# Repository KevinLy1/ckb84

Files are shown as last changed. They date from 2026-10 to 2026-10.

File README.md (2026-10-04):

# CKB84
A DIY custom keyboard with 84 keys with per-key rgb and hotswappable keys.
Raspberry Pi RP2040 MCU.

## Features
- Hotswappable
- Per-key RGB Backlight
- 75% Layout
- QMK and Vial support
- 3D printed / CNC case and plate
- Custom layout : Backspace 2u, Left Shift 2u, Right Shift 2u, ISO Enter, Spacebar 6u

# Images

## Layout

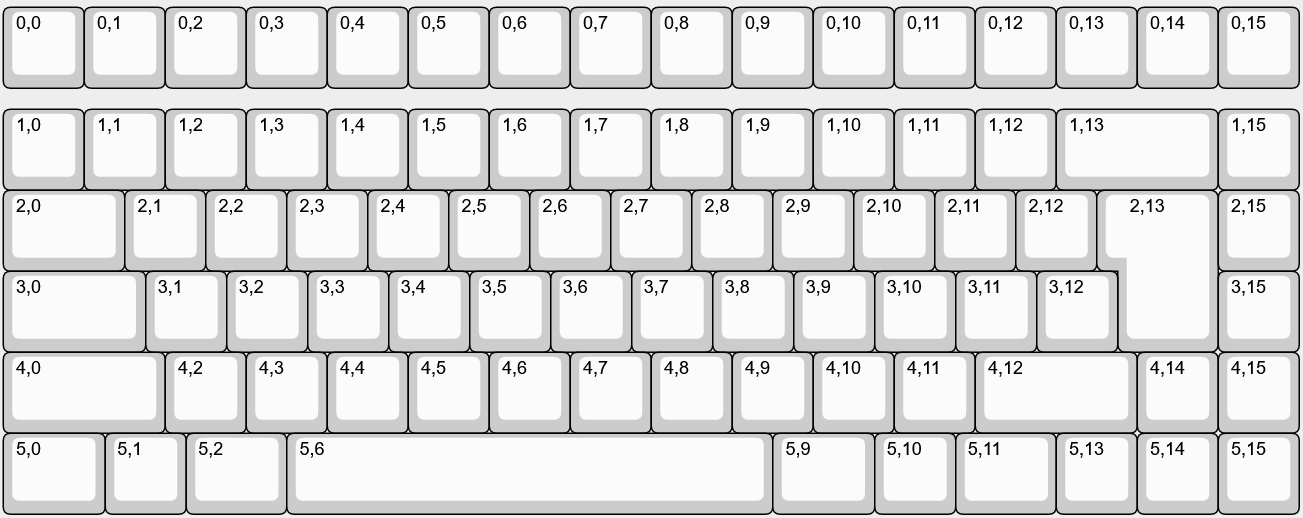
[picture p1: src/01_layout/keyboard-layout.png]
Keyboard layout


## PCB

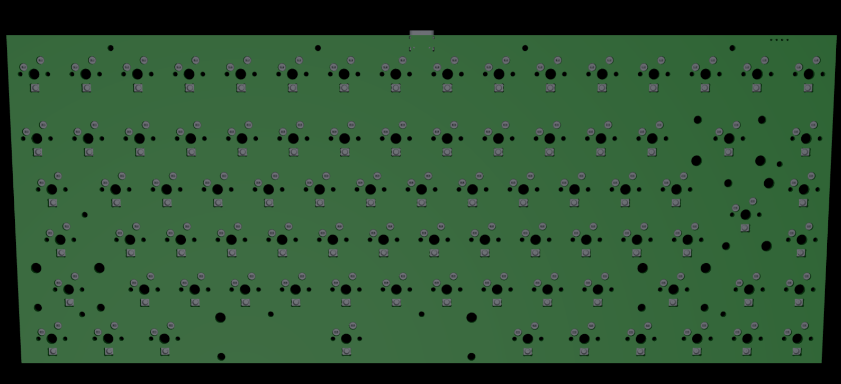
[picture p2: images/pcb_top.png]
PCB Top

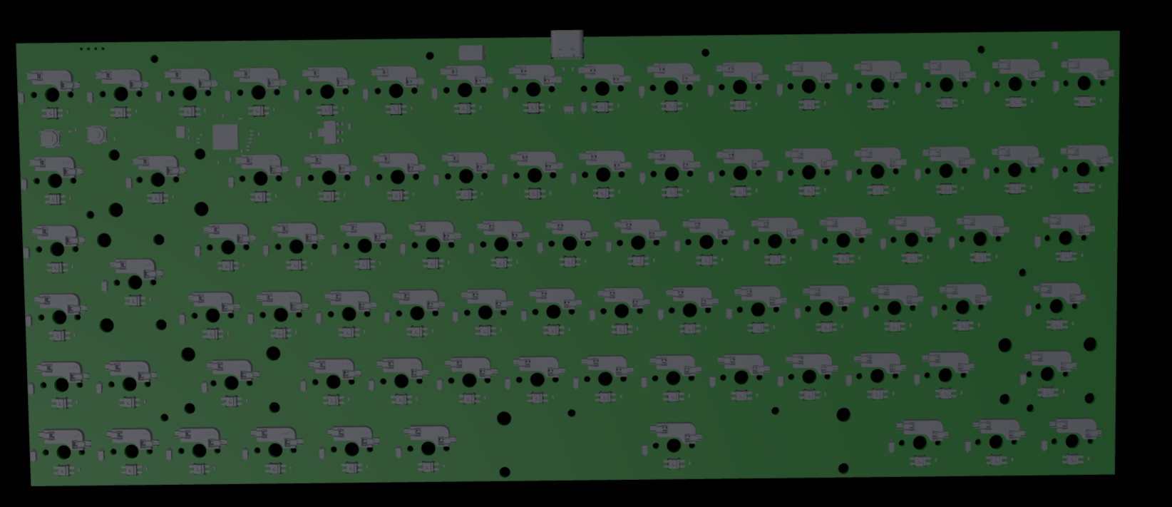
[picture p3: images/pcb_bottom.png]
PCB Bottom


## Case and Plate

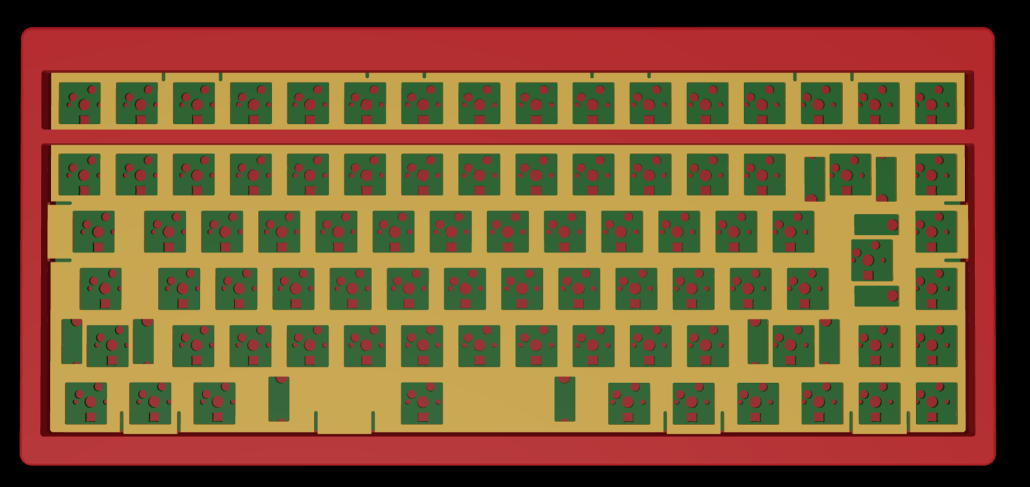
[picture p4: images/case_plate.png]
Case + Plate

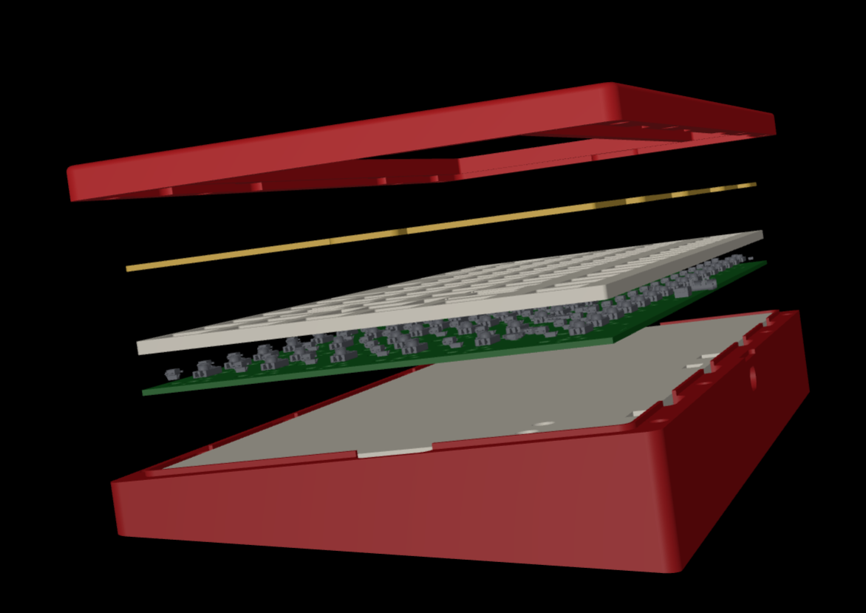
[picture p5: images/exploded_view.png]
Exploded view


## Firmware

See [QMK Reproducible](https://github.com/KevinLy1/qmk_reproducible) -> diy/ckb84.

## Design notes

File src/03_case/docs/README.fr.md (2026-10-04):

# Clavier 75 % sur mesure : boîtier gasket-mount

Boîtier usiné CNC, avec une plaque montée sur joints en Poron et des aimants à la place des vis. Tout est généré à partir du PCB KiCad de `src/02_pcb`, par les scripts build123d de `src/`.

| Caractéristique | Valeur |
|---|---|
| Dimensions | **319,8 × 143,8 mm**, 148 mm de profondeur posé sur le bureau |
| Hauteur (avant / arrière) | **22,1 / 42,1 mm** |
| Angle de frappe | **8°**, donné par le bottom case en coin |
| Masse | top case ≈ 87 g + bottom case ≈ 655 g |
| Montage | 10 pattes de plaque entre des pastilles de Poron |
| Fermeture | 8 paires d'aimants 5 × 2 mm |

## Construction

Depuis `src/03_case`, avec Docker Desktop lancé (environnement figé, build123d 0.13.0) :

```bash
docker compose build
```

```bash
docker compose run --rm cad src/build_all.py
```

```bash
docker compose run --rm cad src/drawings.py
```

```bash
docker compose run --rm cad src/docs_html.py
```

Pour servir le viewer, puis ouvrir `http://localhost:8765/out/viewer.html` :

```bash
docker compose run --rm --service-ports cad -m http.server 8765
```

`build_all.py` vérifie aussi qu'aucune pièce n'en chevauche une autre (tous les résultats doivent valoir `0.0`). Ré-exporter `in/pcb.step` et `in/pcb_full.step` après une modification du PCB demande `kicad-cli` sur la machine.

## Résumé de la conception

Empilement (dessus du PCB = 0, en mm) : PCB −1,51 … 0, plaque 3,5 … 5,0, joints 3,0 (compressés à 2,4), plan de jonction 5,0, dessus 14,0, fond de cavité −6,51.

- **Plaque :** 1,5 mm, découpes de switches 14 × 14 mm, découpes de stabilisateurs Cherry à visser, 10 pattes de joint avec fentes de flexion. Les positions viennent des empreintes KiCad.
- **Top case :** cadre de 9 mm avec un pont de 4,5 mm sur la rangée F.
- **Bottom case :** cavité parallèle à la plaque, rebord de centrage, ouverture USB-C avec une peau de 1 mm pour ne laisser voir que le port, encoche de levage à l'arrière, dessous à 8° avec quatre logements de Ø10,4 pour les patins.
- **Stabilisateurs :** S5 est dans l'orientation Cherry standard, S1–S4 sont tournés de 180° sur le PCB. La plaque suit le PCB, elle s'adapte donc telle quelle.

## Fabrication

- **Top case :** 2 mises en position. **Bottom case :** 3 mises en position (face de jonction, dessous à 8°, ouverture USB-C sur la face arrière).
- **Prototype d'abord :** imprime les STL en 3D pour vérifier l'assemblage avant de payer l'usinage.

## Liste d'achats (amazon.fr)

| # | Article | Qté | Caractéristiques | Recherche sur amazon.fr |
|---|---|---|---|---|
| 1 | Aimants néodyme | 16 (8 paires) + rechange | Disque **5 × 2 mm**, N52 | `aimant néodyme 5x2 mm` (lots de 50) |
| 2 | Mousse pour joints | 20 pastilles | **Poron 3 mm** (ou mousse EPDM 3 mm), adhésive ; à découper en pastilles de 15 × 3 mm | `poron 3mm adhésif` / `joint mousse EPDM adhésif 3 mm` |
| 3 | Patins en caoutchouc | 4 | Patins adhésifs plats **Ø10 × 3 mm** | `patins caoutchouc adhésifs 10 x 3 mm` |
| 4 | Mousse de fond | 1 feuille ≥ 310 × 130 mm | **3 mm**, Poron ou EVA (moins cher) ; découpe selon `case_foam.dxf` | `feuille mousse EVA 3 mm A3` |
| 5 | Mousse PCB/plaque (optionnelle) | 1 feuille | 3–3,5 mm, Poron ou PE, avec les trous des switches | `mousse polyuréthane 3 mm` |
| 6 | Colle | 1 | Cyanoacrylate en **gel** ou époxy bi-composant | `colle cyanoacrylate gel` / `Araldite` |

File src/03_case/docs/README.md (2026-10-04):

# Custom 75 % keyboard: gasket-mount case

CNC-machined case with a gasket-mounted plate (Poron pads) and magnets instead of screws. Everything is generated from the KiCad board in `src/02_pcb` by the build123d scripts in `src/`.

| Feature | Value |
|---|---|
| Outside size | **319.8 × 143.8 mm**, 148 mm deep on the desk |
| Height (front / back) | **22.1 / 42.1 mm** |
| Typing angle | **8°**, from the wedge-shaped bottom case |
| Mass | top case ≈ 87 g + bottom case ≈ 655 g |
| Mount | 10 plate tabs between Poron pads |
| Closure | 8 pairs of 5 × 2 mm magnets |

## Build

From `src/03_case`, with Docker Desktop running (pinned environment, build123d 0.13.0):

```bash
docker compose build
```

```bash
docker compose run --rm cad src/build_all.py
```

```bash
docker compose run --rm cad src/drawings.py
```

```bash
docker compose run --rm cad src/docs_html.py
```

Serve the viewer, then open `http://localhost:8765/out/viewer.html`:

```bash
docker compose run --rm --service-ports cad -m http.server 8765
```

`build_all.py` also checks that no two parts overlap (all results must be `0.0`). Re-exporting `in/pcb.step` and `in/pcb_full.step` after a PCB change needs `kicad-cli` on the host.

## Design summary

Stack-up (PCB top = 0, in mm): PCB −1.51 … 0, plate 3.5 … 5.0, gasket pads 3.0 (compressed to 2.4), parting plane 5.0, top surface 14.0, cavity floor −6.51.

- **Plate:** 1.5 mm, 14 × 14 mm switch cutouts, Cherry screw-in stabilizer cutouts, 10 gasket tabs with flex slots. Positions come from the KiCad footprints.
- **Top case:** 9 mm frame with a 4.5 mm F-row bridge.
- **Bottom case:** cavity parallel to the plate, alignment lip, USB-C slot with a 1 mm skin so only the port shows, pry notch at the back, underside at 8° with four Ø10.4 recesses for rubber feet.
- **Stabilizers:** S5 is in the standard Cherry orientation, S1–S4 are rotated 180° on the PCB. The plate follows the PCB, so it fits as is.

## Manufacturing

- **Top case:** 2 setups. **Bottom case:** 3 setups (parting face, 8° underside, USB-C slot on the back face).
- **Prototype first:** 3D-print the STLs to check the fit before paying for CNC.

## Hardware list (amazon.fr)

Search terms are in French where that finds the right product more easily.

| # | Item | Qty | Specification | Search on amazon.fr |
|---|---|---|---|---|
| 1 | Neodymium magnets | 16 (8 pairs) + spares | Disc **5 × 2 mm**, N52 | `aimant néodyme 5x2 mm` (packs of 50) |
| 2 | Gasket foam | 20 pads | **Poron 3 mm** (or EPDM sponge 3 mm), self-adhesive; cut into 15 × 3 mm pads | `poron 3mm adhésif` / `joint mousse EPDM adhésif 3 mm` |
| 3 | Rubber feet | 4 | **Ø10 × 3 mm** flat self-adhesive bumpers | `patins caoutchouc adhésifs 10 x 3 mm` |
| 4 | Case foam | 1 sheet ≥ 310 × 130 mm | **3 mm** Poron, or EVA as a cheaper option; cut from `case_foam.dxf` | `feuille mousse EVA 3 mm A3` |
| 5 | PCB/plate foam (optional) | 1 sheet | 3–3.5 mm Poron or PE, with switch holes | `mousse polyuréthane 3 mm` |
| 6 | Glue | 1 | Cyanoacrylate **gel** or 2-part epoxy | `colle cyanoacrylate gel` / `Araldite` |

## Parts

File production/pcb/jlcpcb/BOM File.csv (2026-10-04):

Designator | Footprint | Quantity | Value | LCSC Part #
C1 | CP_EIA-7343-31_Kemet-D | 1 | 470uF | C7229
C10, C17, C2, C3, C4, C5, C6, C7, C8, C9, LC1, LC10, LC11, LC12, LC13, LC14, LC15, LC16, LC17, LC18, LC19, LC2, LC20, LC21, LC22, LC23, LC24, LC25, LC26, LC27, LC28, LC29, LC3, LC30, LC31, LC32, LC33, LC34, LC35, LC36, LC37, LC38, LC39, LC4, LC40, LC41, LC42, LC43, LC44, LC45, LC46, LC47, LC48, LC49, LC5, LC50, LC51, LC52, LC53, LC54, LC55, LC56, LC57, LC58, LC59, LC6, LC60, LC61, LC62, LC63, LC64, LC65, LC66, LC67, LC68, LC69, LC7, LC70, LC71, LC72, LC73, LC74, LC75, LC76, LC77, LC78, LC79, LC8, LC80, LC81, LC82, LC83, LC84, LC9 | 0402 | 94 | 100nF | C1525
C11, C12 | 0402 | 2 | 1u | C52923
C13, C14 | 0603 | 2 | 22u | C59461
C15, C16 | 0402 | 2 | 15pF | C1548
D1, D10, D11, D12, D13, D14, D15, D16, D17, D18, D19, D2, D20, D21, D22, D23, D24, D25, D26, D27, D28, D29, D3, D30, D31, D32, D33, D34, D35, D36, D37, D38, D39, D4, D40, D41, D42, D43, D44, D45, D46, D47, D48, D49, D5, D50, D51, D52, D53, D54, D55, D56, D57, D58, D59, D6, D60, D61, D62, D63, D64, D65, D66, D67, D68, D69, D7, D70, D71, D72, D73, D74, D75, D76, D77, D78, D79, D8, D80, D81, D82, D83, D84, D9 | D_SOD-123 | 84 | D | C33221
J1 | USB_C_Receptacle_HRO_TYPE-C-31-M-12 | 1 | USB_C_Receptacle_USB2.0 | C165948
LED1, LED10, LED11, LED12, LED13, LED14, LED15, LED16, LED17, LED18, LED19, LED2, LED20, LED21, LED22, LED23, LED24, LED25, LED26, LED27, LED28, LED29, LED3, LED30, LED31, LED32, LED33, LED34, LED35, LED36, LED37, LED38, LED39, LED4, LED40, LED41, LED42, LED43, LED44, LED45, LED46, LED47, LED48, LED49, LED5, LED50, LED51, LED52, LED53, LED54, LED55, LED56, LED57, LED58, LED59, LED6, LED60, LED61, LED62, LED63, LED64, LED65, LED66, LED67, LED68, LED69, LED7, LED70, LED71, LED72, LED73, LED74, LED75, LED76, LED77, LED78, LED79, LED8, LED80, LED81, LED82, LED83, LED84, LED9 | LED_MX_6028R | 84 | MX_SK6812MINI-E | C5149201
MX1, MX10, MX11, MX12, MX13, MX14, MX15, MX16, MX17, MX18, MX19, MX2, MX20, MX21, MX22, MX23, MX24, MX25, MX26, MX27, MX28, MX29, MX3, MX30, MX31, MX33, MX34, MX35, MX36, MX37, MX38, MX39, MX4, MX40, MX41, MX42, MX43, MX44, MX45, MX46, MX48, MX49, MX5, MX50, MX51, MX52, MX53, MX54, MX55, MX56, MX57, MX58, MX59, MX6, MX60, MX61, MX62, MX63, MX64, MX65, MX66, MX67, MX68, MX69, MX7, MX70, MX71, MX72, MX73, MX74, MX76, MX78, MX8, MX80, MX82, MX83, MX84, MX9 | SW_MX_HS_CPG151101S11_1u | 78 | MX_SW_HS | C41430893
MX32 | SW_MX_HS_CPG151101S11_1.5u | 1 | MX_SW_HS | C41430893
MX47 | SW_MX_HS_CPG151101S11_1.75u | 1 | MX_SW_HS | C41430893
MX75, MX77, MX79, MX81 | SW_MX_HS_CPG151101S11_1.25u | 4 | MX_SW_HS | C41430893
R1, R2, R3 | 0402 | 3 | 5.1k | C25905
R4, R5 | 0402 | 2 | 27 | C226392
R6, R8 | 0402 | 2 | 1k | C11702
RST1, RST2 | SW_SPST_SKQG_WithStem | 2 | SW | C5140332
U1 | SOT-353_SC-70-5 | 1 | SN74LV1T34DCK | C48543212
U2 | SOT-223-3_TabPin2 | 1 | AMS1117-3.3 | C6186
U3 | SOT-23-6 | 1 | USBLC6-2SC6 | C558442
U4 | QFN-56-1EP_7x7mm_P0.4mm_EP3.2x3.2mm | 1 | RP2040 | C2040
U5 | SOIC127P790X216-8N | 1 | W25Q128JVS | C97521
Y1 | Crystal_SMD_3225-4Pin_3.2x2.5mm | 1 | ABM8-272-T3 | C20625731

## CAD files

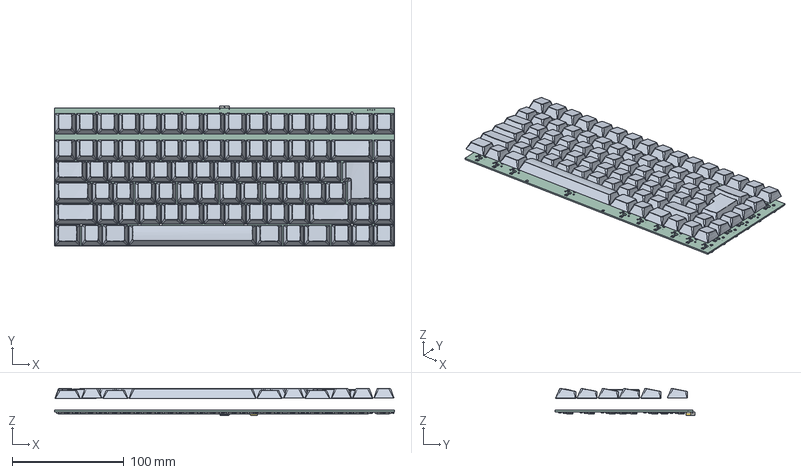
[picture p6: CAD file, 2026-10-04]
src/03_case/in/pcb_full.step
304.8 x 125.5 x 24.3 mm
C_0402_1005Metric x 98
D_SOD-123 x 84
R_0402_1005Metric x 8
C_0603_1608Metric x 2
Contact x 168
r4_100 x 73
LED_SK6812MINI-E v2 x 84
r3_125 x 4
QFN-56-1EP_7x7mm_P0.4mm_EP3.2x3.2mm
ConPins
PcbPins
Mold
Frame
SW_SPST_TL3342 x 2
r4_200 x 3
r4_175
r4_150
r4_600
Crystal_SMD_3225-4Pin_3.2x2.5mm
CP_EIA_7343_31_Kemet_D
SOT-23-6
SOT-223
r3_iso
SOT-353_SC-70-5
Custom_keyboard_PCB

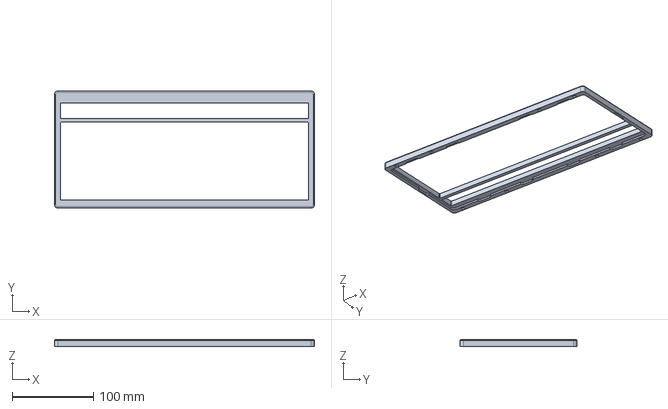
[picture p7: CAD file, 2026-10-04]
production/enclosure/top_case.step
319.8 x 143.8 x 9.00 mm

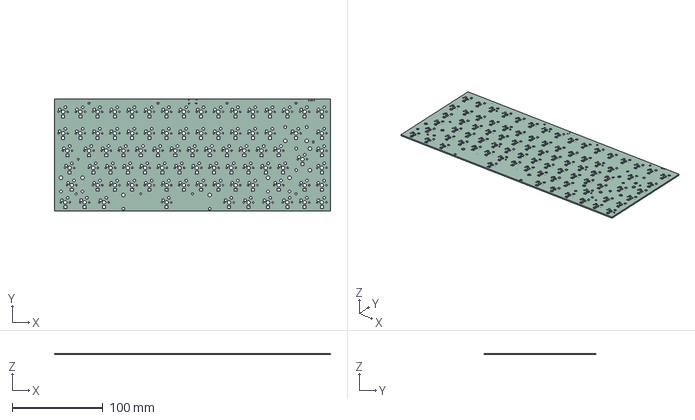
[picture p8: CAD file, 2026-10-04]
src/03_case/in/pcb.step
304.8 x 123.8 x 1.51 mm

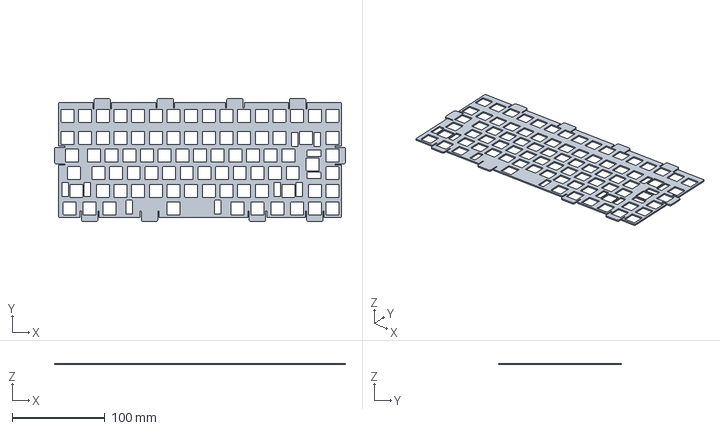
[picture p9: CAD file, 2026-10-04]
production/enclosure/plate.step
313.8 x 132.8 x 1.50 mm

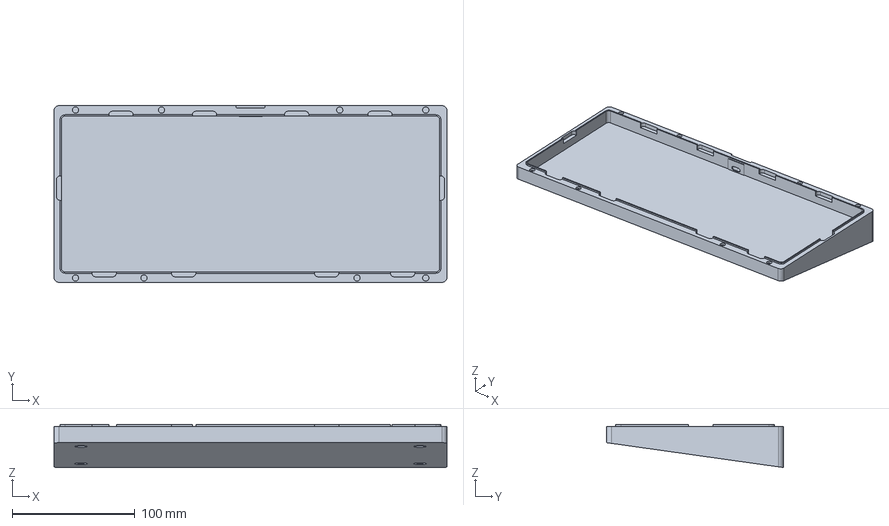
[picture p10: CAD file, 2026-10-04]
production/enclosure/bottom_case.step
319.8 x 143.8 x 35.0 mm

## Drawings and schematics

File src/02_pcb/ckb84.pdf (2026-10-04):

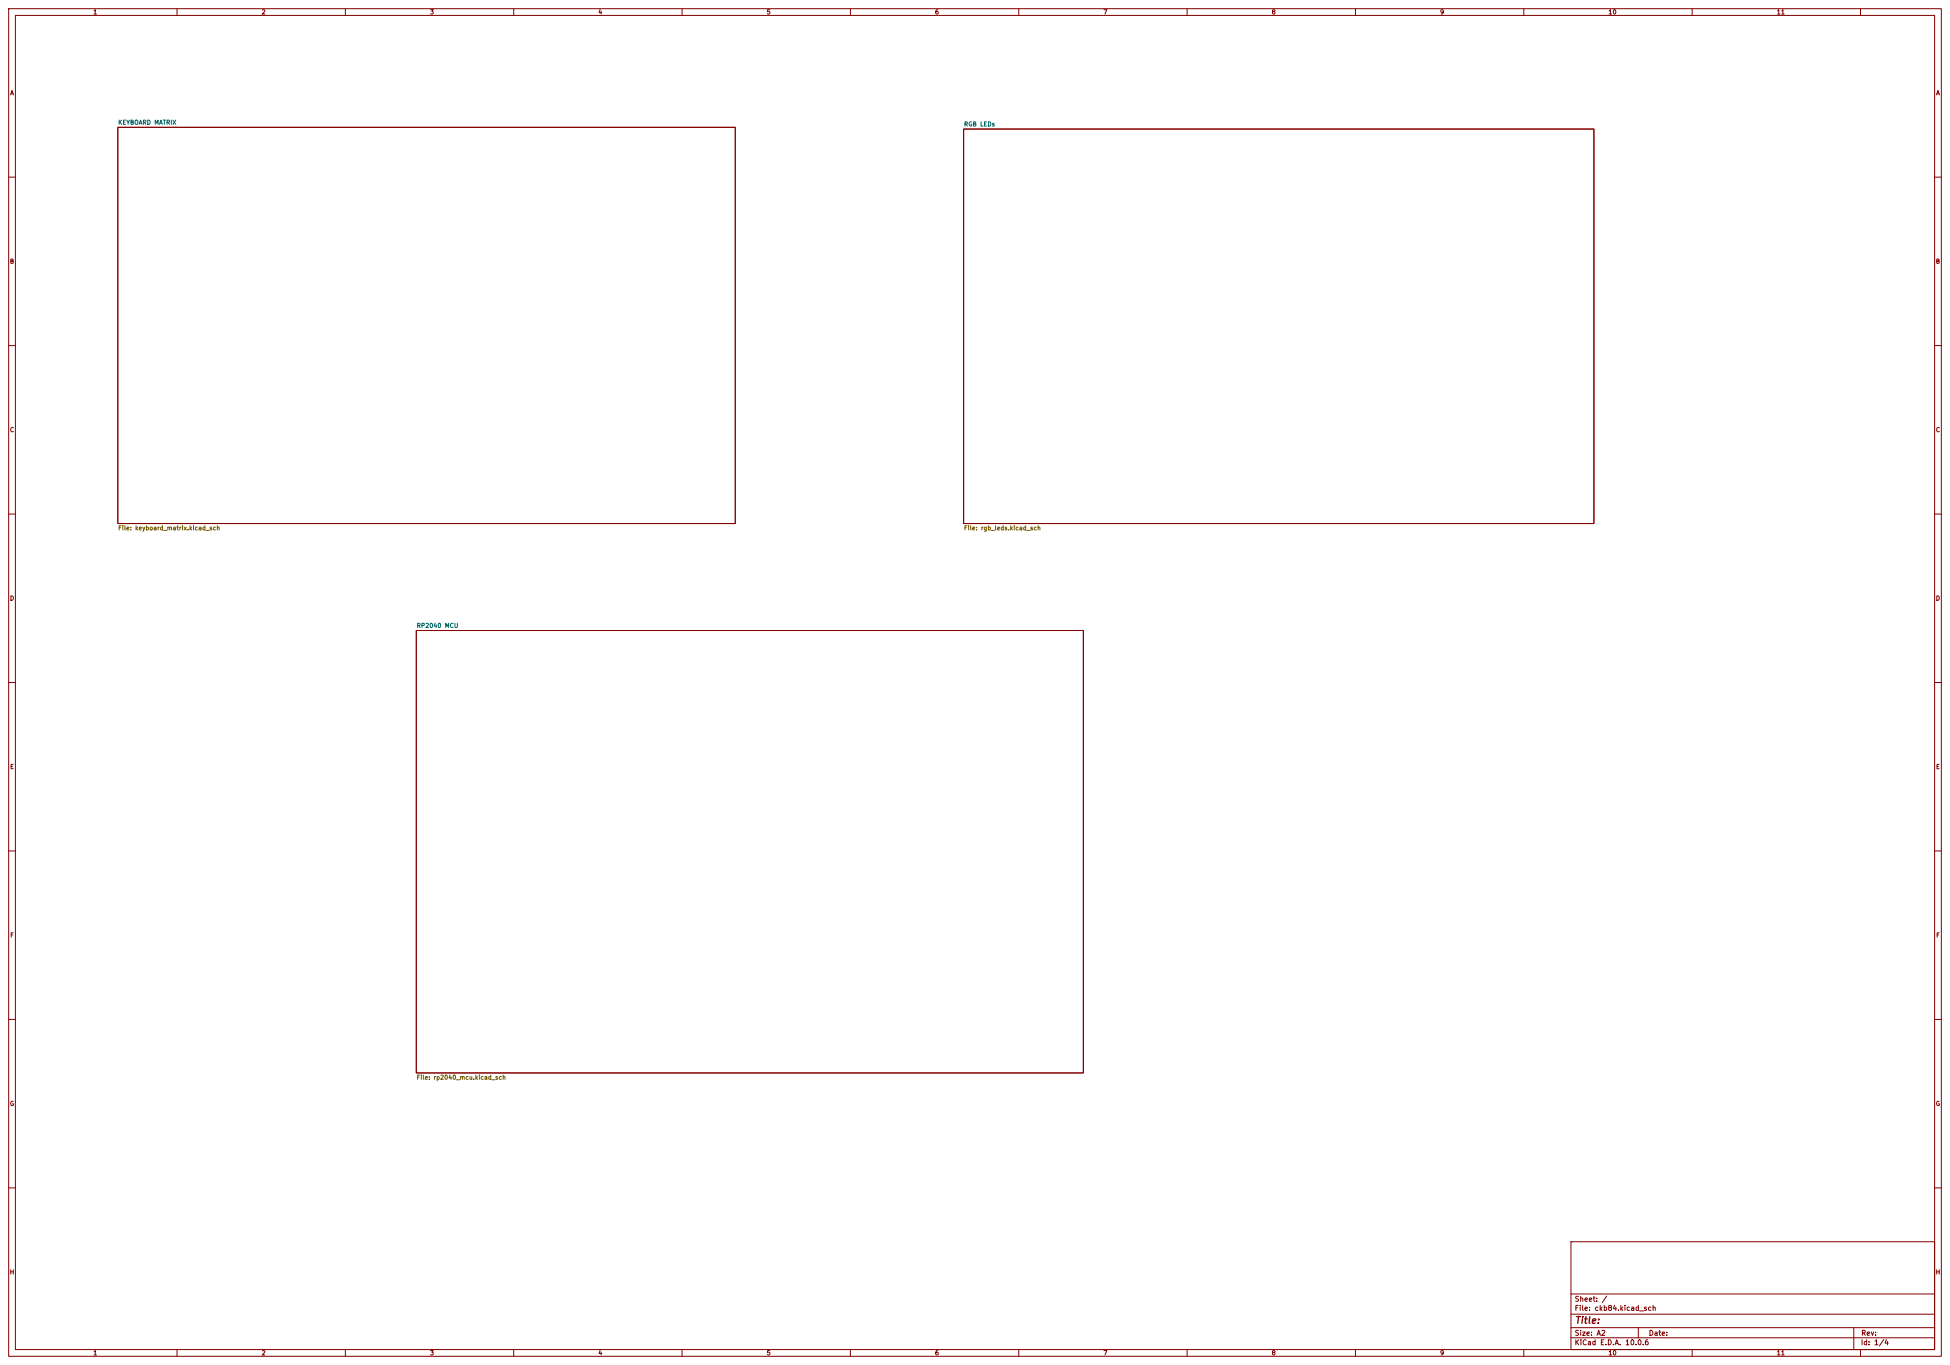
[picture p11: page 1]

Size: A2 | Rev:
KiCad E.D.A. 10.0.6 | Id: 1/4

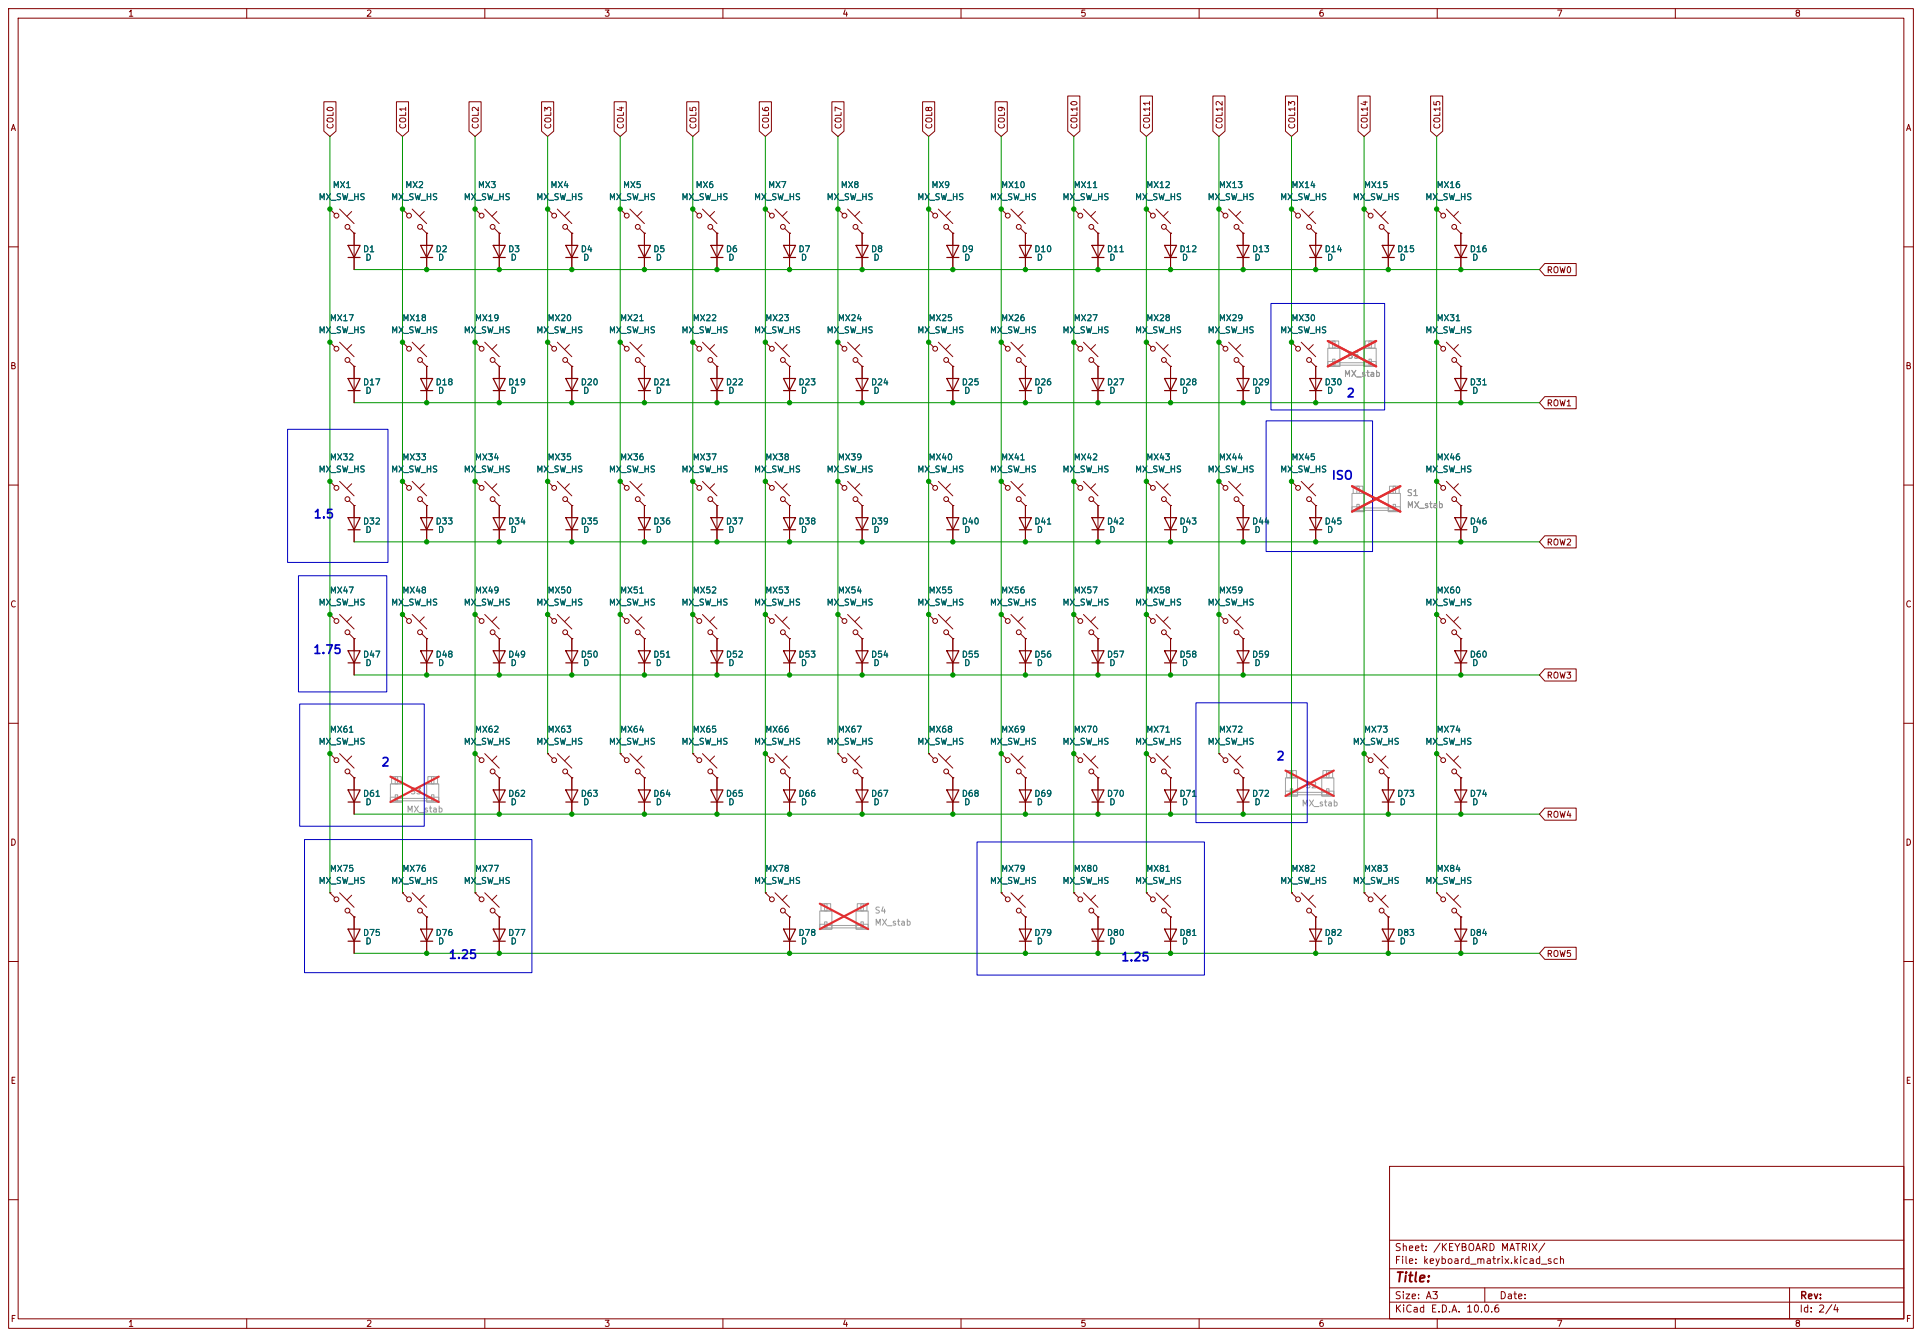
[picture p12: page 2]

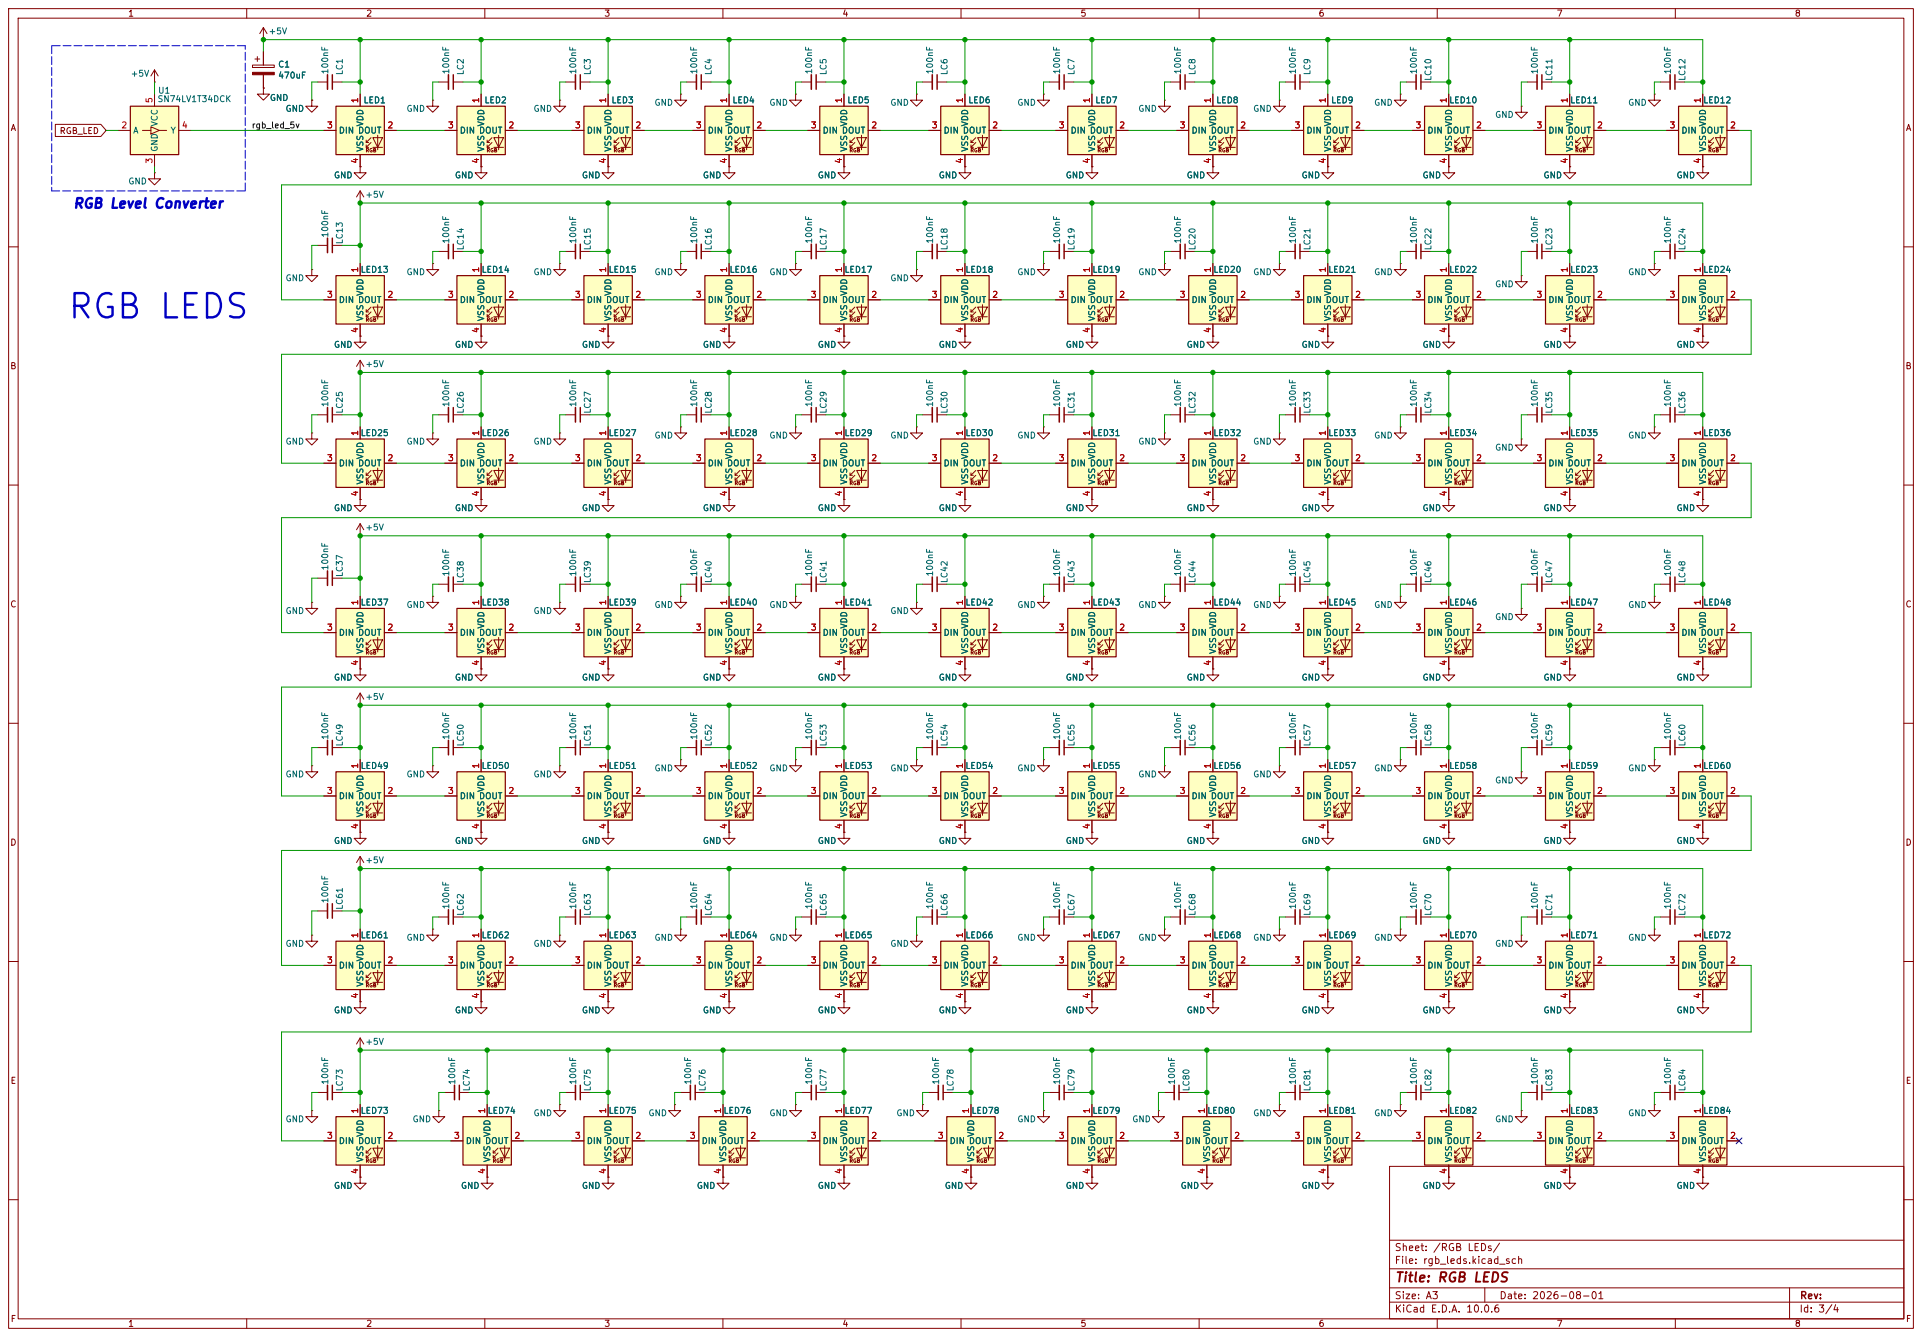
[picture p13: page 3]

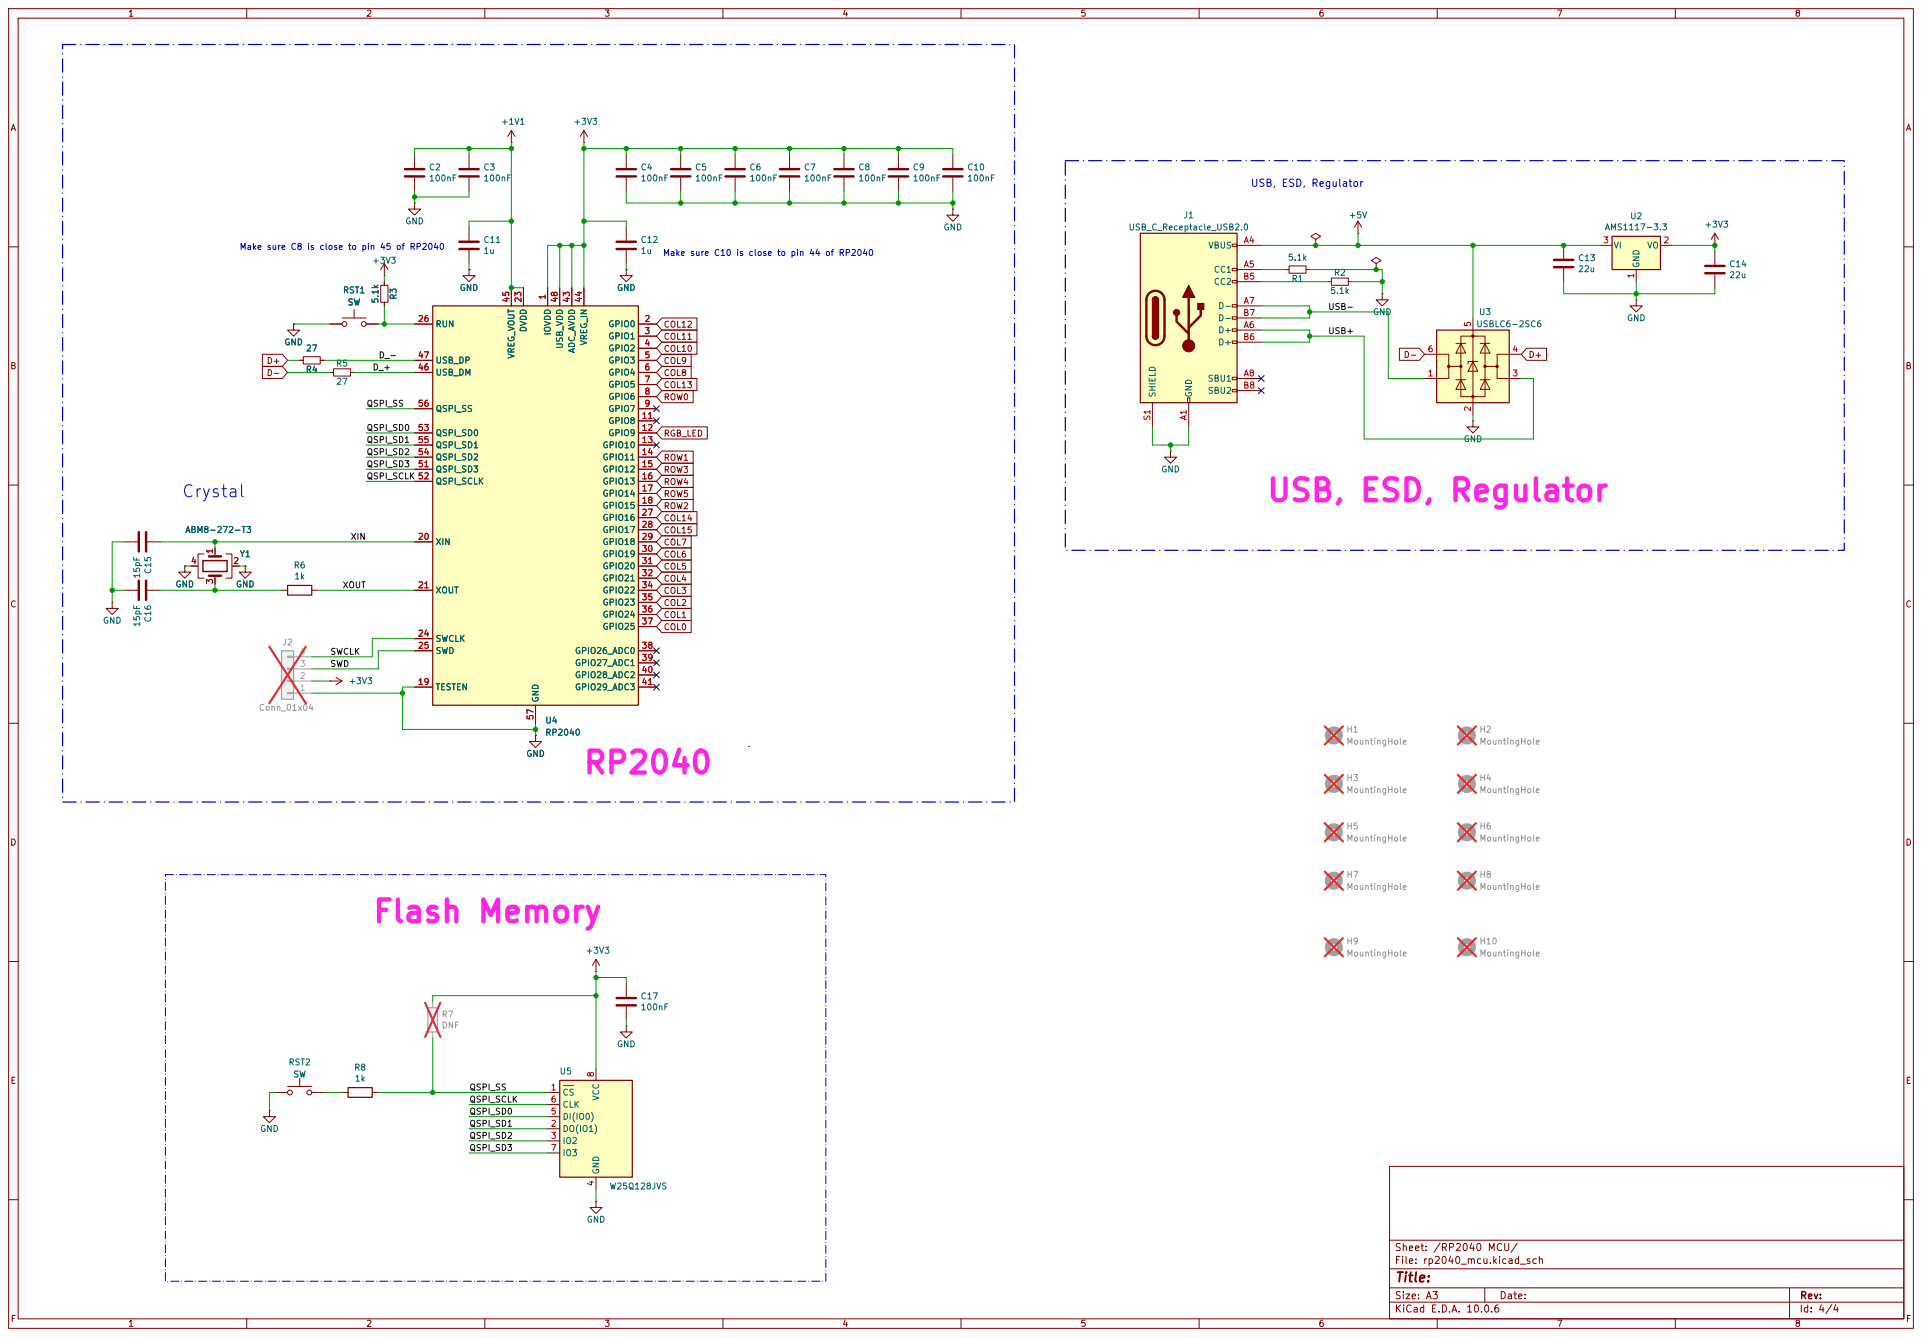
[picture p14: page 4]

Make sure C8 is close to pin 45 of RP2040 Crystal

Make sure C10 is close to pin 44 of RP2040 Flash Memory

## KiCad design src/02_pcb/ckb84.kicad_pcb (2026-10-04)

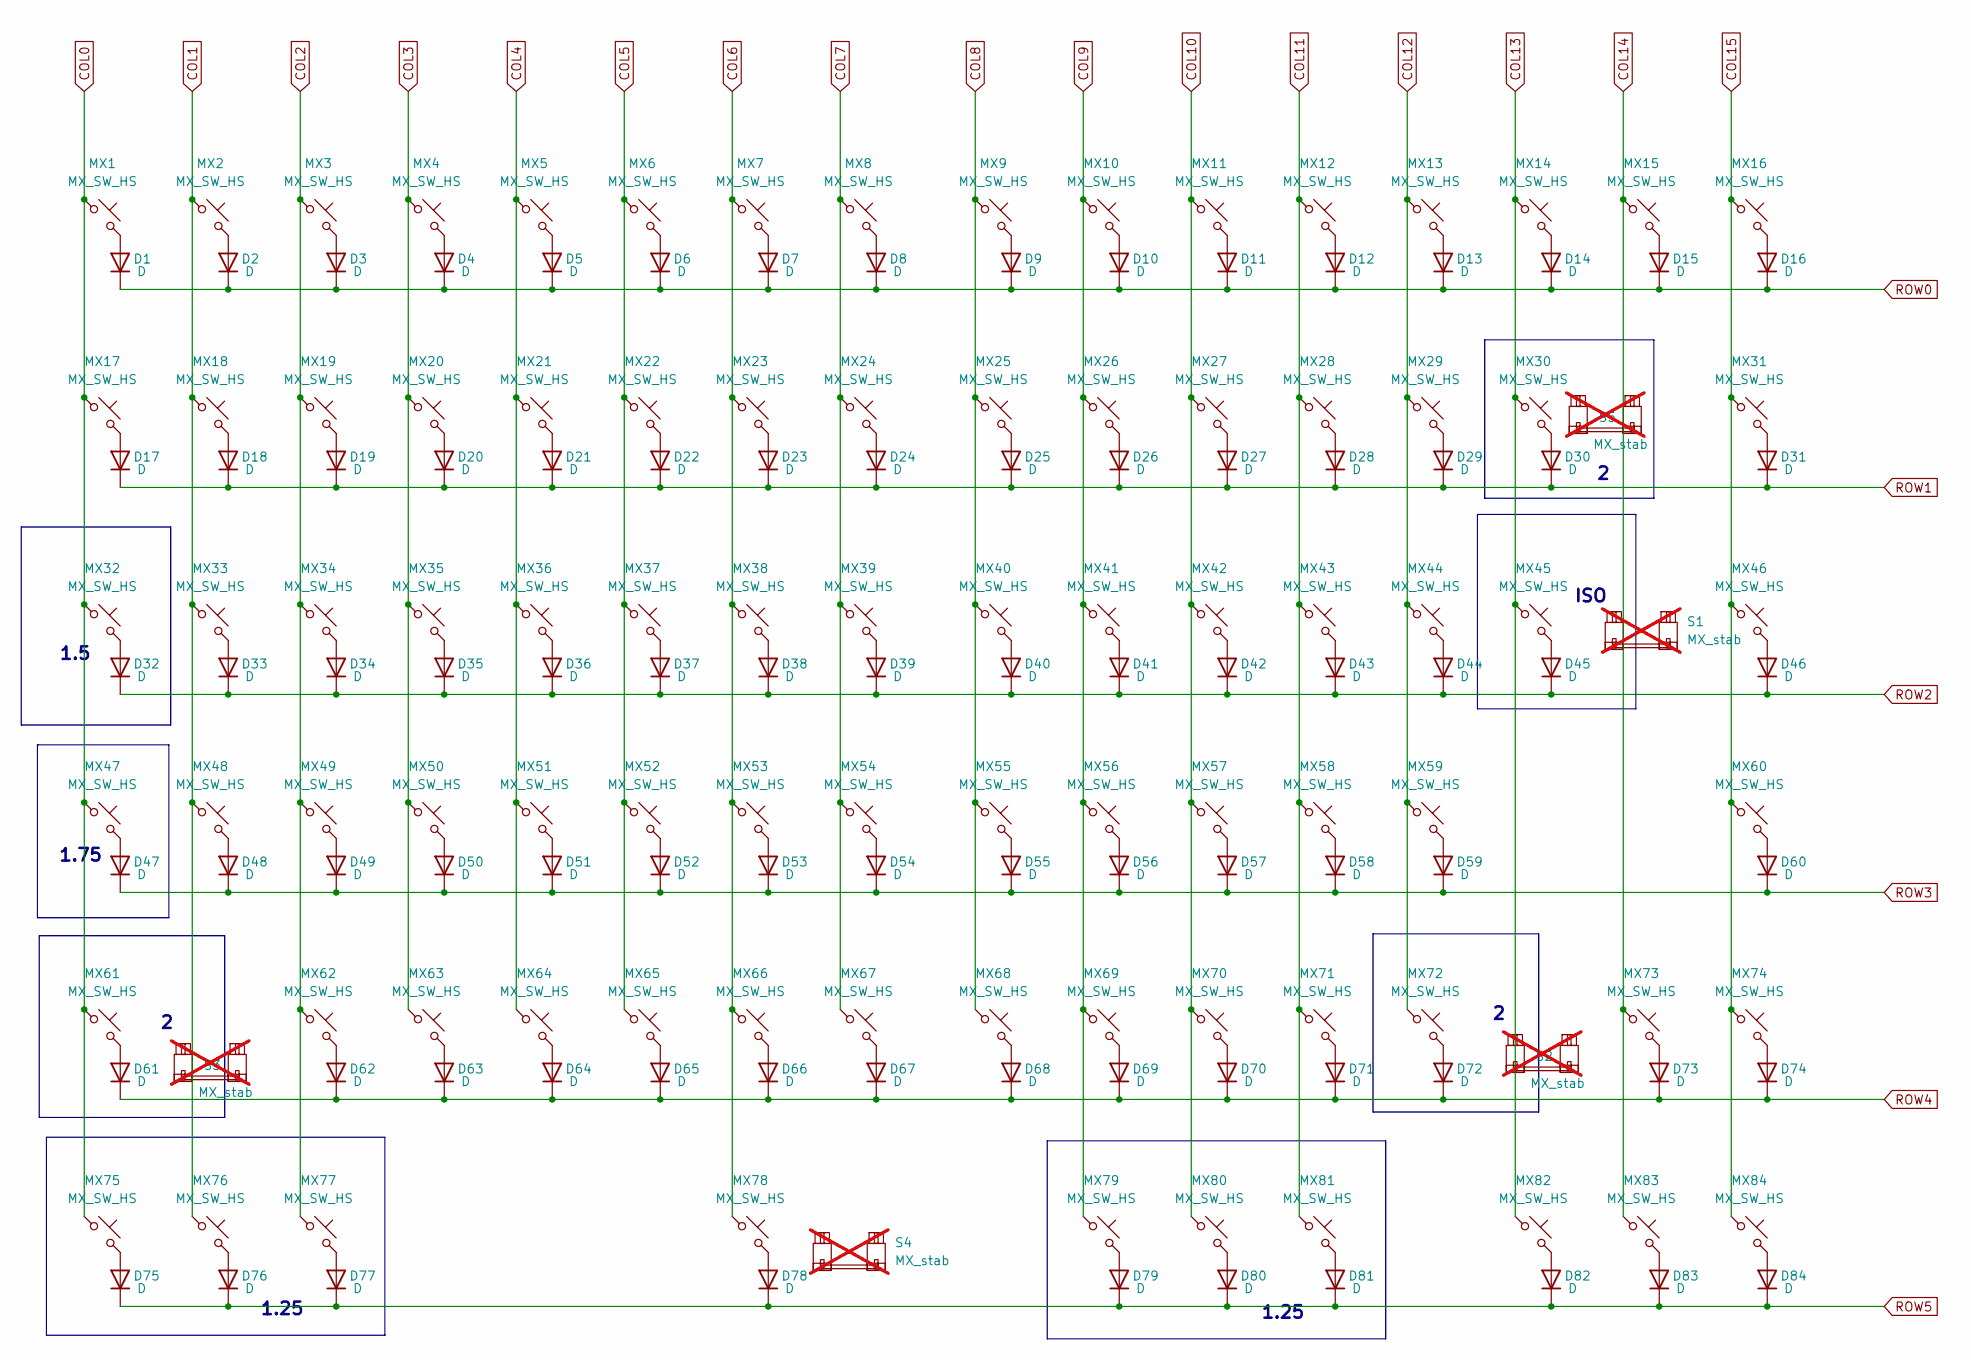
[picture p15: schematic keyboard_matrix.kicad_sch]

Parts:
D1, D2, D3, D4, D5, D6, D7, D8, D9, D10, D11, D12, D13, D14, D15, D16, D17, D18, D19, D20, D21, D22, D23, D24, D25, D26, D27, D28, D29, D30, D31, D32, D33, D34, D35, D36, D37, D38, D39, D40, D41, D42, D43, D44, D45, D46, D47, D48, D49, D50, D51, D52, D53, D54, D55, D56, D57, D58, D59, D60, D61, D62, D63, D64, D65, D66, D67, D68, D69, D70, D71, D72, D73, D74, D75, D76, D77, D78, D79, D80, D81, D82, D83, D84: D; D_SOD-123; MFR.Part # SOD1F7; LCSC C33221
MX1, MX2, MX3, MX4, MX5, MX6, MX7, MX8, MX9, MX10, MX11, MX12, MX13, MX14, MX15, MX16, MX17, MX18, MX19, MX20, MX21, MX22, MX23, MX24, MX25, MX26, MX27, MX28, MX29, MX30, MX31, MX33, MX34, MX35, MX36, MX37, MX38, MX39, MX40, MX41, MX42, MX43, MX44, MX45, MX46, MX48, MX49, MX50, MX51, MX52, MX53, MX54, MX55, MX56, MX57, MX58, MX59, MX60, MX61, MX62, MX63, MX64, MX65, MX66, MX67, MX68, MX69, MX70, MX71, MX72, MX73, MX74, MX76, MX78, MX80, MX82, MX83, MX84: MX_SW_HS; SW_MX_HS_CPG151101S11_1u; MFR.Part # CPG151101S11-16; LCSC C41430893
MX32: MX_SW_HS; SW_MX_HS_CPG151101S11_1.5u; MFR.Part # CPG151101S11-16; LCSC C41430893
MX47: MX_SW_HS; SW_MX_HS_CPG151101S11_1.75u; MFR.Part # CPG151101S11-16; LCSC C41430893
MX75, MX77, MX79, MX81: MX_SW_HS; SW_MX_HS_CPG151101S11_1.25u; MFR.Part # CPG151101S11-16; LCSC C41430893
S1: MX_stab; STAB_MX_ISO; MFR.Part # DNP; JLCPCB part# DNP; not fitted
S2, S3, S5: MX_stab; STAB_MX_P_2u; MFR.Part # DNP; JLCPCB part# DNP; not fitted
S4: MX_stab; STAB_MX_6u; MFR.Part # DNP; JLCPCB part# DNP; not fitted

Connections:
COL0: MX1.1, MX17.1, MX32.1, MX47.1, MX61.1, MX75.1; also elsewhere on the board
COL1: MX2.1, MX18.1, MX33.1, MX48.1, MX76.1; also elsewhere on the board
COL2: MX3.1, MX19.1, MX34.1, MX49.1, MX62.1, MX77.1; also elsewhere on the board
COL3: MX4.1, MX20.1, MX35.1, MX50.1, MX63.1; also elsewhere on the board
COL4: MX5.1, MX21.1, MX36.1, MX51.1, MX64.1; also elsewhere on the board
COL5: MX6.1, MX22.1, MX37.1, MX52.1, MX65.1; also elsewhere on the board
COL6: MX7.1, MX23.1, MX38.1, MX53.1, MX66.1, MX78.1; also elsewhere on the board
COL7: MX8.1, MX24.1, MX39.1, MX54.1, MX67.1; also elsewhere on the board
COL8: MX9.1, MX25.1, MX40.1, MX55.1, MX68.1; also elsewhere on the board
COL9: MX10.1, MX26.1, MX41.1, MX56.1, MX69.1, MX79.1; also elsewhere on the board
COL10: MX11.1, MX27.1, MX42.1, MX57.1, MX70.1, MX80.1; also elsewhere on the board
COL11: MX12.1, MX28.1, MX43.1, MX58.1, MX71.1, MX81.1; also elsewhere on the board
COL12: MX13.1, MX29.1, MX44.1, MX59.1, MX72.1; also elsewhere on the board
COL13: MX14.1, MX30.1, MX45.1, MX82.1; also elsewhere on the board
COL14: MX15.1, MX73.1, MX83.1; also elsewhere on the board
COL15: MX16.1, MX31.1, MX46.1, MX60.1, MX74.1, MX84.1; also elsewhere on the board
unnamed: D1.2 (A), MX1.2
unnamed: D2.2 (A), MX2.2
unnamed: D3.2 (A), MX3.2
unnamed: D4.2 (A), MX4.2
unnamed: D5.2 (A), MX5.2
unnamed: D6.2 (A), MX6.2
unnamed: D7.2 (A), MX7.2
unnamed: D8.2 (A), MX8.2
unnamed: D9.2 (A), MX9.2
unnamed: D10.2 (A), MX10.2
unnamed: D11.2 (A), MX11.2
unnamed: D12.2 (A), MX12.2
unnamed: D13.2 (A), MX13.2
unnamed: D14.2 (A), MX14.2
unnamed: D15.2 (A), MX15.2
unnamed: D16.2 (A), MX16.2
unnamed: D17.2 (A), MX17.2
unnamed: D18.2 (A), MX18.2
unnamed: D19.2 (A), MX19.2
unnamed: D20.2 (A), MX20.2
unnamed: D21.2 (A), MX21.2
unnamed: D22.2 (A), MX22.2
unnamed: D23.2 (A), MX23.2
unnamed: D24.2 (A), MX24.2
unnamed: D25.2 (A), MX25.2
unnamed: D26.2 (A), MX26.2
unnamed: D27.2 (A), MX27.2
unnamed: D28.2 (A), MX28.2
unnamed: D29.2 (A), MX29.2
unnamed: D30.2 (A), MX30.2
unnamed: D31.2 (A), MX31.2
unnamed: D32.2 (A), MX32.2
unnamed: D33.2 (A), MX33.2
unnamed: D34.2 (A), MX34.2
unnamed: D35.2 (A), MX35.2
unnamed: D36.2 (A), MX36.2
unnamed: D37.2 (A), MX37.2
unnamed: D38.2 (A), MX38.2
unnamed: D39.2 (A), MX39.2
unnamed: D40.2 (A), MX40.2
unnamed: D41.2 (A), MX41.2
unnamed: D42.2 (A), MX42.2
unnamed: D43.2 (A), MX43.2
unnamed: D44.2 (A), MX44.2
unnamed: D45.2 (A), MX45.2
unnamed: D46.2 (A), MX46.2
unnamed: D47.2 (A), MX47.2
unnamed: D48.2 (A), MX48.2
unnamed: D49.2 (A), MX49.2
unnamed: D50.2 (A), MX50.2
unnamed: D51.2 (A), MX51.2
unnamed: D52.2 (A), MX52.2
unnamed: D53.2 (A), MX53.2
unnamed: D54.2 (A), MX54.2
unnamed: D55.2 (A), MX55.2
unnamed: D56.2 (A), MX56.2
unnamed: D57.2 (A), MX57.2
unnamed: D58.2 (A), MX58.2
unnamed: D59.2 (A), MX59.2
unnamed: D60.2 (A), MX60.2
unnamed: D61.2 (A), MX61.2
unnamed: D62.2 (A), MX62.2
unnamed: D63.2 (A), MX63.2
unnamed: D64.2 (A), MX64.2
unnamed: D65.2 (A), MX65.2
unnamed: D66.2 (A), MX66.2
unnamed: D67.2 (A), MX67.2
unnamed: D68.2 (A), MX68.2
unnamed: D69.2 (A), MX69.2
unnamed: D70.2 (A), MX70.2
unnamed: D71.2 (A), MX71.2
unnamed: D72.2 (A), MX72.2
unnamed: D73.2 (A), MX73.2
unnamed: D74.2 (A), MX74.2
unnamed: D75.2 (A), MX75.2
unnamed: D76.2 (A), MX76.2
unnamed: D77.2 (A), MX77.2
unnamed: D78.2 (A), MX78.2
unnamed: D79.2 (A), MX79.2
unnamed: D80.2 (A), MX80.2
unnamed: D81.2 (A), MX81.2
unnamed: D82.2 (A), MX82.2
unnamed: D83.2 (A), MX83.2
unnamed: D84.2 (A), MX84.2
ROW0: D1.1 (K), D2.1 (K), D3.1 (K), D4.1 (K), D5.1 (K), D6.1 (K), D7.1 (K), D8.1 (K), D9.1 (K), D10.1 (K), D11.1 (K), D12.1 (K), D13.1 (K), D14.1 (K), D15.1 (K), D16.1 (K); also elsewhere on the board
ROW1: D17.1 (K), D18.1 (K), D19.1 (K), D20.1 (K), D21.1 (K), D22.1 (K), D23.1 (K), D24.1 (K), D25.1 (K), D26.1 (K), D27.1 (K), D28.1 (K), D29.1 (K), D30.1 (K), D31.1 (K); also elsewhere on the board
ROW2: D32.1 (K), D33.1 (K), D34.1 (K), D35.1 (K), D36.1 (K), D37.1 (K), D38.1 (K), D39.1 (K), D40.1 (K), D41.1 (K), D42.1 (K), D43.1 (K), D44.1 (K), D45.1 (K), D46.1 (K); also elsewhere on the board
ROW3: D47.1 (K), D48.1 (K), D49.1 (K), D50.1 (K), D51.1 (K), D52.1 (K), D53.1 (K), D54.1 (K), D55.1 (K), D56.1 (K), D57.1 (K), D58.1 (K), D59.1 (K), D60.1 (K); also elsewhere on the board
ROW4: D61.1 (K), D62.1 (K), D63.1 (K), D64.1 (K), D65.1 (K), D66.1 (K), D67.1 (K), D68.1 (K), D69.1 (K), D70.1 (K), D71.1 (K), D72.1 (K), D73.1 (K), D74.1 (K); also elsewhere on the board
ROW5: D75.1 (K), D76.1 (K), D77.1 (K), D78.1 (K), D79.1 (K), D80.1 (K), D81.1 (K), D82.1 (K), D83.1 (K), D84.1 (K); also elsewhere on the board

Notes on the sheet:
ISO
1.75
1.25
1.5

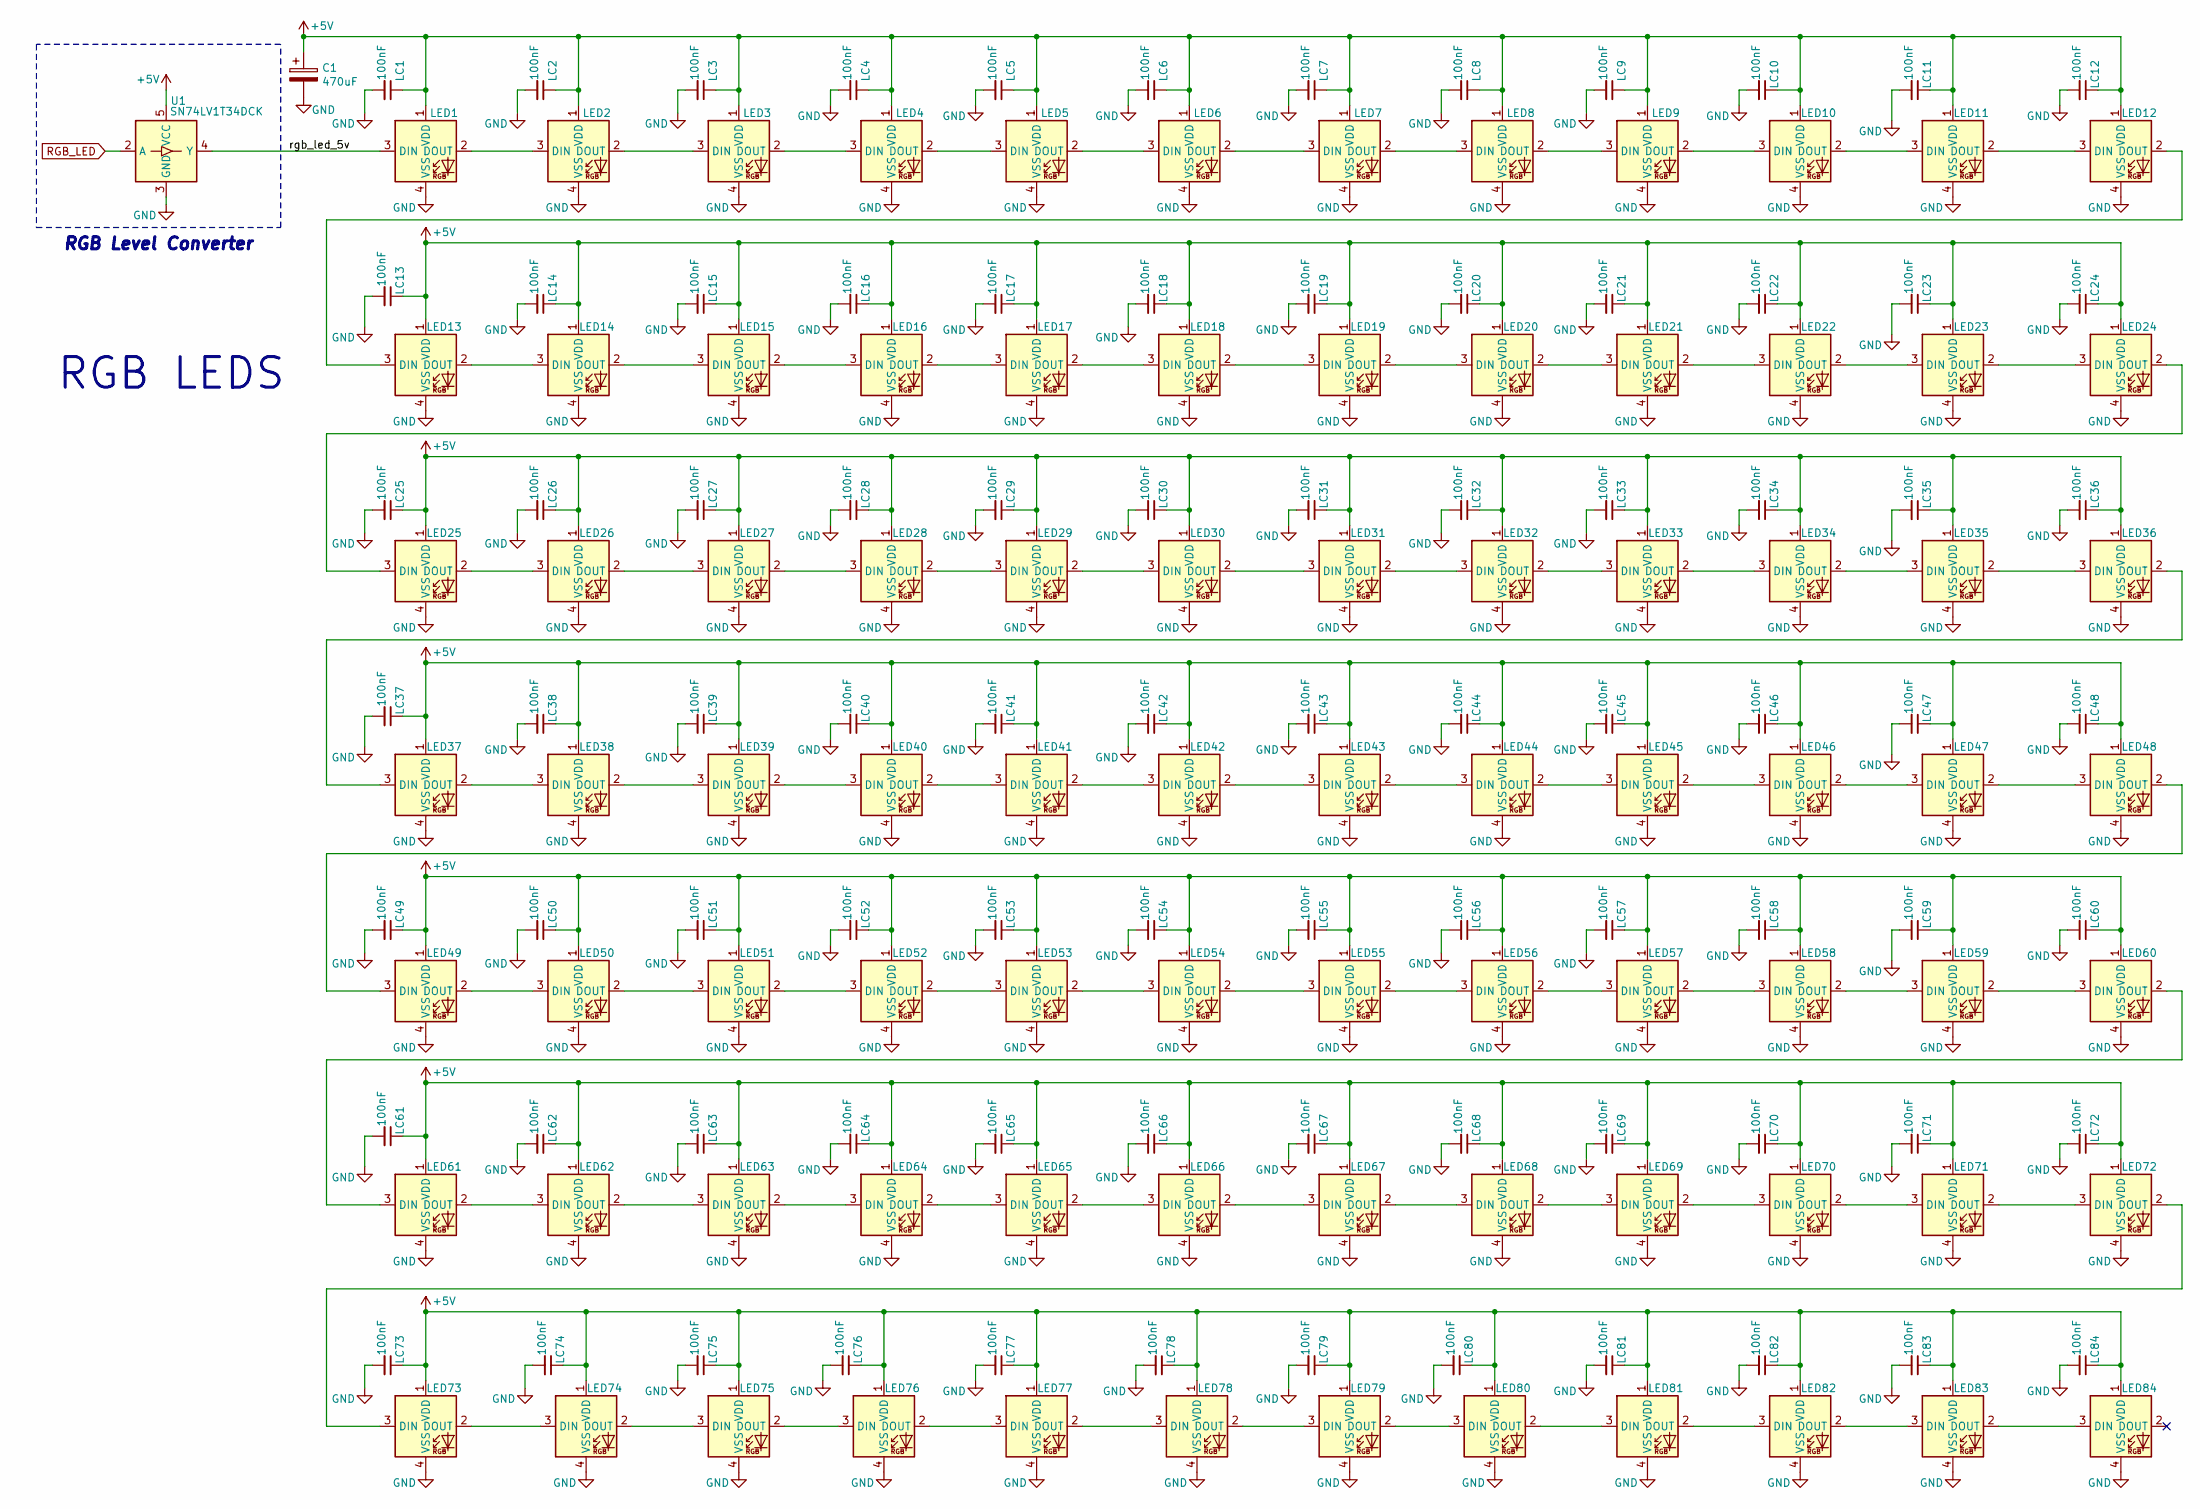
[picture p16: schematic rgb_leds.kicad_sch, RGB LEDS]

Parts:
C1: 470uF; CP_EIA-7343-31_Kemet-D; MFR.Part # TAJD477K006RNJ; JLCPCB Part # C7229
LC1, LC2, LC3, LC4, LC5, LC6, LC7, LC8, LC9, LC10, LC11, LC12, LC13, LC14, LC15, LC16, LC17, LC18, LC19, LC20, LC21, LC22, LC23, LC24, LC25, LC26, LC27, LC28, LC29, LC30, LC31, LC32, LC33, LC34, LC35, LC36, LC37, LC38, LC39, LC40, LC41, LC42, LC43, LC44, LC45, LC46, LC47, LC48, LC49, LC50, LC51, LC52, LC53, LC54, LC55, LC56, LC57, LC58, LC59, LC60, LC61, LC62, LC63, LC64, LC65, LC66, LC67, LC68, LC69, LC70, LC71, LC72, LC73, LC74, LC75, LC76, LC77, LC78, LC79, LC80, LC81, LC82, LC83, LC84: 100nF; C_0402_1005Metric; LCSC C1525
LED1, LED2, LED3, LED4, LED5, LED6, LED7, LED8, LED9, LED10, LED11, LED12, LED13, LED14, LED15, LED16, LED17, LED18, LED19, LED20, LED21, LED22, LED23, LED24, LED25, LED26, LED27, LED28, LED29, LED30, LED31, LED32, LED33, LED34, LED35, LED36, LED37, LED38, LED39, LED40, LED41, LED42, LED43, LED44, LED45, LED46, LED47, LED48, LED49, LED50, LED51, LED52, LED53, LED54, LED55, LED56, LED57, LED58, LED59, LED60, LED61, LED62, LED63, LED64, LED65, LED66, LED67, LED68, LED69, LED70, LED71, LED72, LED73, LED74, LED75, LED76, LED77, LED78, LED79, LED80, LED81, LED82, LED83, LED84: MX_SK6812MINI-E; LED_MX_6028R; LCSC C5149201
U1: SN74LV1T34DCK; SOT-353_SC-70-5; LCSC C48543212

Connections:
+5V: C1.1, LC1.1, LC2.1, LC3.1, LC4.1, LC5.1, LC6.1, LC7.1, LC8.1, LC9.1, LC10.1, LC11.1, LC12.1, LC13.1, LC14.1, LC15.1, LC16.1, LC17.1, LC18.1, LC19.1, LC20.1, LC21.1, LC22.1, LC23.1, LC24.1, LC25.1, LC26.1, LC27.1, LC28.1, LC29.1, LC30.1, LC31.1, LC32.1, LC33.1, LC34.1, LC35.1, LC36.1, LC37.1, LC38.1, LC39.1, LC40.1, LC41.1, LC42.1, LC43.1, LC44.1, LC45.1, LC46.1, LC47.1, LC48.1, LC49.1, LC50.1, LC51.1, LC52.1, LC53.1, LC54.1, LC55.1, LC56.1, LC57.1, LC58.1, LC59.1, LC60.1, LC61.1, LC62.1, LC63.1, LC64.1, LC65.1, LC66.1, LC67.1, LC68.1, LC69.1, LC70.1, LC71.1, LC72.1, LC73.1, LC74.1, LC75.1, LC76.1, LC77.1, LC78.1, LC79.1, LC80.1, LC81.1, LC82.1, LC83.1, LC84.1, LED1.1 (VDD), LED2.1 (VDD), LED3.1 (VDD), LED4.1 (VDD), LED5.1 (VDD), LED6.1 (VDD), LED7.1 (VDD), LED8.1 (VDD), LED9.1 (VDD), LED10.1 (VDD), LED11.1 (VDD), LED12.1 (VDD), LED13.1 (VDD), LED14.1 (VDD), LED15.1 (VDD), LED16.1 (VDD), LED17.1 (VDD), LED18.1 (VDD), LED19.1 (VDD), LED20.1 (VDD), LED21.1 (VDD), LED22.1 (VDD), LED23.1 (VDD), LED24.1 (VDD), LED25.1 (VDD), LED26.1 (VDD), LED27.1 (VDD), LED28.1 (VDD), LED29.1 (VDD), LED30.1 (VDD), LED31.1 (VDD), LED32.1 (VDD), LED33.1 (VDD), LED34.1 (VDD), LED35.1 (VDD), LED36.1 (VDD), LED37.1 (VDD), LED38.1 (VDD), LED39.1 (VDD), LED40.1 (VDD), LED41.1 (VDD), LED42.1 (VDD), LED43.1 (VDD), LED44.1 (VDD), LED45.1 (VDD), LED46.1 (VDD), LED47.1 (VDD), LED48.1 (VDD), LED49.1 (VDD), LED50.1 (VDD), LED51.1 (VDD), LED52.1 (VDD), LED53.1 (VDD), LED54.1 (VDD), LED55.1 (VDD), LED56.1 (VDD), LED57.1 (VDD), LED58.1 (VDD), LED59.1 (VDD), LED60.1 (VDD), LED61.1 (VDD), LED62.1 (VDD), LED63.1 (VDD), LED64.1 (VDD), LED65.1 (VDD), LED66.1 (VDD), LED67.1 (VDD), LED68.1 (VDD), LED69.1 (VDD), LED70.1 (VDD), LED71.1 (VDD), LED72.1 (VDD), LED73.1 (VDD), LED74.1 (VDD), LED75.1 (VDD), LED76.1 (VDD), LED77.1 (VDD), LED78.1 (VDD), LED79.1 (VDD), LED80.1 (VDD), LED81.1 (VDD), LED82.1 (VDD), LED83.1 (VDD), LED84.1 (VDD), U1.5 (VCC); also elsewhere on the board
/RGB LEDs/rgb_led_5v: LED1.3 (DIN), U1.4 (Y)
GND: C1.2, LC1.2, LC2.2, LC3.2, LC4.2, LC5.2, LC6.2, LC7.2, LC8.2, LC9.2, LC10.2, LC11.2, LC12.2, LC13.2, LC14.2, LC15.2, LC16.2, LC17.2, LC18.2, LC19.2, LC20.2, LC21.2, LC22.2, LC23.2, LC24.2, LC25.2, LC26.2, LC27.2, LC28.2, LC29.2, LC30.2, LC31.2, LC32.2, LC33.2, LC34.2, LC35.2, LC36.2, LC37.2, LC38.2, LC39.2, LC40.2, LC41.2, LC42.2, LC43.2, LC44.2, LC45.2, LC46.2, LC47.2, LC48.2, LC49.2, LC50.2, LC51.2, LC52.2, LC53.2, LC54.2, LC55.2, LC56.2, LC57.2, LC58.2, LC59.2, LC60.2, LC61.2, LC62.2, LC63.2, LC64.2, LC65.2, LC66.2, LC67.2, LC68.2, LC69.2, LC70.2, LC71.2, LC72.2, LC73.2, LC74.2, LC75.2, LC76.2, LC77.2, LC78.2, LC79.2, LC80.2, LC81.2, LC82.2, LC83.2, LC84.2, LED1.4 (VSS), LED2.4 (VSS), LED3.4 (VSS), LED4.4 (VSS), LED5.4 (VSS), LED6.4 (VSS), LED7.4 (VSS), LED8.4 (VSS), LED9.4 (VSS), LED10.4 (VSS), LED11.4 (VSS), LED12.4 (VSS), LED13.4 (VSS), LED14.4 (VSS), LED15.4 (VSS), LED16.4 (VSS), LED17.4 (VSS), LED18.4 (VSS), LED19.4 (VSS), LED20.4 (VSS), LED21.4 (VSS), LED22.4 (VSS), LED23.4 (VSS), LED24.4 (VSS), LED25.4 (VSS), LED26.4 (VSS), LED27.4 (VSS), LED28.4 (VSS), LED29.4 (VSS), LED30.4 (VSS), LED31.4 (VSS), LED32.4 (VSS), LED33.4 (VSS), LED34.4 (VSS), LED35.4 (VSS), LED36.4 (VSS), LED37.4 (VSS), LED38.4 (VSS), LED39.4 (VSS), LED40.4 (VSS), LED41.4 (VSS), LED42.4 (VSS), LED43.4 (VSS), LED44.4 (VSS), LED45.4 (VSS), LED46.4 (VSS), LED47.4 (VSS), LED48.4 (VSS), LED49.4 (VSS), LED50.4 (VSS), LED51.4 (VSS), LED52.4 (VSS), LED53.4 (VSS), LED54.4 (VSS), LED55.4 (VSS), LED56.4 (VSS), LED57.4 (VSS), LED58.4 (VSS), LED59.4 (VSS), LED60.4 (VSS), LED61.4 (VSS), LED62.4 (VSS), LED63.4 (VSS), LED64.4 (VSS), LED65.4 (VSS), LED66.4 (VSS), LED67.4 (VSS), LED68.4 (VSS), LED69.4 (VSS), LED70.4 (VSS), LED71.4 (VSS), LED72.4 (VSS), LED73.4 (VSS), LED74.4 (VSS), LED75.4 (VSS), LED76.4 (VSS), LED77.4 (VSS), LED78.4 (VSS), LED79.4 (VSS), LED80.4 (VSS), LED81.4 (VSS), LED82.4 (VSS), LED83.4 (VSS), LED84.4 (VSS), U1.3 (GND); also elsewhere on the board
unnamed: LED1.2 (DOUT), LED2.3 (DIN)
unnamed: LED2.2 (DOUT), LED3.3 (DIN)
unnamed: LED3.2 (DOUT), LED4.3 (DIN)
unnamed: LED4.2 (DOUT), LED5.3 (DIN)
unnamed: LED5.2 (DOUT), LED6.3 (DIN)
unnamed: LED6.2 (DOUT), LED7.3 (DIN)
unnamed: LED7.2 (DOUT), LED8.3 (DIN)
unnamed: LED8.2 (DOUT), LED9.3 (DIN)
unnamed: LED9.2 (DOUT), LED10.3 (DIN)
unnamed: LED10.2 (DOUT), LED11.3 (DIN)
unnamed: LED11.2 (DOUT), LED12.3 (DIN)
unnamed: LED12.2 (DOUT), LED13.3 (DIN)
unnamed: LED13.2 (DOUT), LED14.3 (DIN)
unnamed: LED14.2 (DOUT), LED15.3 (DIN)
unnamed: LED15.2 (DOUT), LED16.3 (DIN)
unnamed: LED16.2 (DOUT), LED17.3 (DIN)
unnamed: LED17.2 (DOUT), LED18.3 (DIN)
unnamed: LED18.2 (DOUT), LED19.3 (DIN)
unnamed: LED19.2 (DOUT), LED20.3 (DIN)
unnamed: LED20.2 (DOUT), LED21.3 (DIN)
unnamed: LED21.2 (DOUT), LED22.3 (DIN)
unnamed: LED22.2 (DOUT), LED23.3 (DIN)
unnamed: LED23.2 (DOUT), LED24.3 (DIN)
unnamed: LED24.2 (DOUT), LED25.3 (DIN)
unnamed: LED25.2 (DOUT), LED26.3 (DIN)
unnamed: LED26.2 (DOUT), LED27.3 (DIN)
unnamed: LED27.2 (DOUT), LED28.3 (DIN)
unnamed: LED28.2 (DOUT), LED29.3 (DIN)
unnamed: LED29.2 (DOUT), LED30.3 (DIN)
unnamed: LED30.2 (DOUT), LED31.3 (DIN)
unnamed: LED31.2 (DOUT), LED32.3 (DIN)
unnamed: LED32.2 (DOUT), LED33.3 (DIN)
unnamed: LED33.2 (DOUT), LED34.3 (DIN)
unnamed: LED34.2 (DOUT), LED35.3 (DIN)
unnamed: LED35.2 (DOUT), LED36.3 (DIN)
unnamed: LED36.2 (DOUT), LED37.3 (DIN)
unnamed: LED37.2 (DOUT), LED38.3 (DIN)
unnamed: LED38.2 (DOUT), LED39.3 (DIN)
unnamed: LED39.2 (DOUT), LED40.3 (DIN)
unnamed: LED40.2 (DOUT), LED41.3 (DIN)
unnamed: LED41.2 (DOUT), LED42.3 (DIN)
unnamed: LED42.2 (DOUT), LED43.3 (DIN)
unnamed: LED43.2 (DOUT), LED44.3 (DIN)
unnamed: LED44.2 (DOUT), LED45.3 (DIN)
unnamed: LED45.2 (DOUT), LED46.3 (DIN)
unnamed: LED46.2 (DOUT), LED47.3 (DIN)
unnamed: LED47.2 (DOUT), LED48.3 (DIN)
unnamed: LED48.2 (DOUT), LED49.3 (DIN)
unnamed: LED49.2 (DOUT), LED50.3 (DIN)
unnamed: LED50.2 (DOUT), LED51.3 (DIN)
unnamed: LED51.2 (DOUT), LED52.3 (DIN)
unnamed: LED52.2 (DOUT), LED53.3 (DIN)
unnamed: LED53.2 (DOUT), LED54.3 (DIN)
unnamed: LED54.2 (DOUT), LED55.3 (DIN)
unnamed: LED55.2 (DOUT), LED56.3 (DIN)
unnamed: LED56.2 (DOUT), LED57.3 (DIN)
unnamed: LED57.2 (DOUT), LED58.3 (DIN)
unnamed: LED58.2 (DOUT), LED59.3 (DIN)
unnamed: LED59.2 (DOUT), LED60.3 (DIN)
unnamed: LED60.2 (DOUT), LED61.3 (DIN)
unnamed: LED61.2 (DOUT), LED62.3 (DIN)
unnamed: LED62.2 (DOUT), LED63.3 (DIN)
unnamed: LED63.2 (DOUT), LED64.3 (DIN)
unnamed: LED64.2 (DOUT), LED65.3 (DIN)
unnamed: LED65.2 (DOUT), LED66.3 (DIN)
unnamed: LED66.2 (DOUT), LED67.3 (DIN)
unnamed: LED67.2 (DOUT), LED68.3 (DIN)
unnamed: LED68.2 (DOUT), LED69.3 (DIN)
unnamed: LED69.2 (DOUT), LED70.3 (DIN)
unnamed: LED70.2 (DOUT), LED71.3 (DIN)
unnamed: LED71.2 (DOUT), LED72.3 (DIN)
unnamed: LED72.2 (DOUT), LED73.3 (DIN)
unnamed: LED73.2 (DOUT), LED74.3 (DIN)
unnamed: LED74.2 (DOUT), LED75.3 (DIN)
unnamed: LED75.2 (DOUT), LED76.3 (DIN)
unnamed: LED76.2 (DOUT), LED77.3 (DIN)
unnamed: LED77.2 (DOUT), LED78.3 (DIN)
unnamed: LED78.2 (DOUT), LED79.3 (DIN)
unnamed: LED79.2 (DOUT), LED80.3 (DIN)
unnamed: LED80.2 (DOUT), LED81.3 (DIN)
unnamed: LED81.2 (DOUT), LED82.3 (DIN)
unnamed: LED82.2 (DOUT), LED83.3 (DIN)
unnamed: LED83.2 (DOUT), LED84.3 (DIN)
RGB_LED: U1.2 (A); also elsewhere on the board

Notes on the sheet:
RGB Level Converter
RGB LEDS

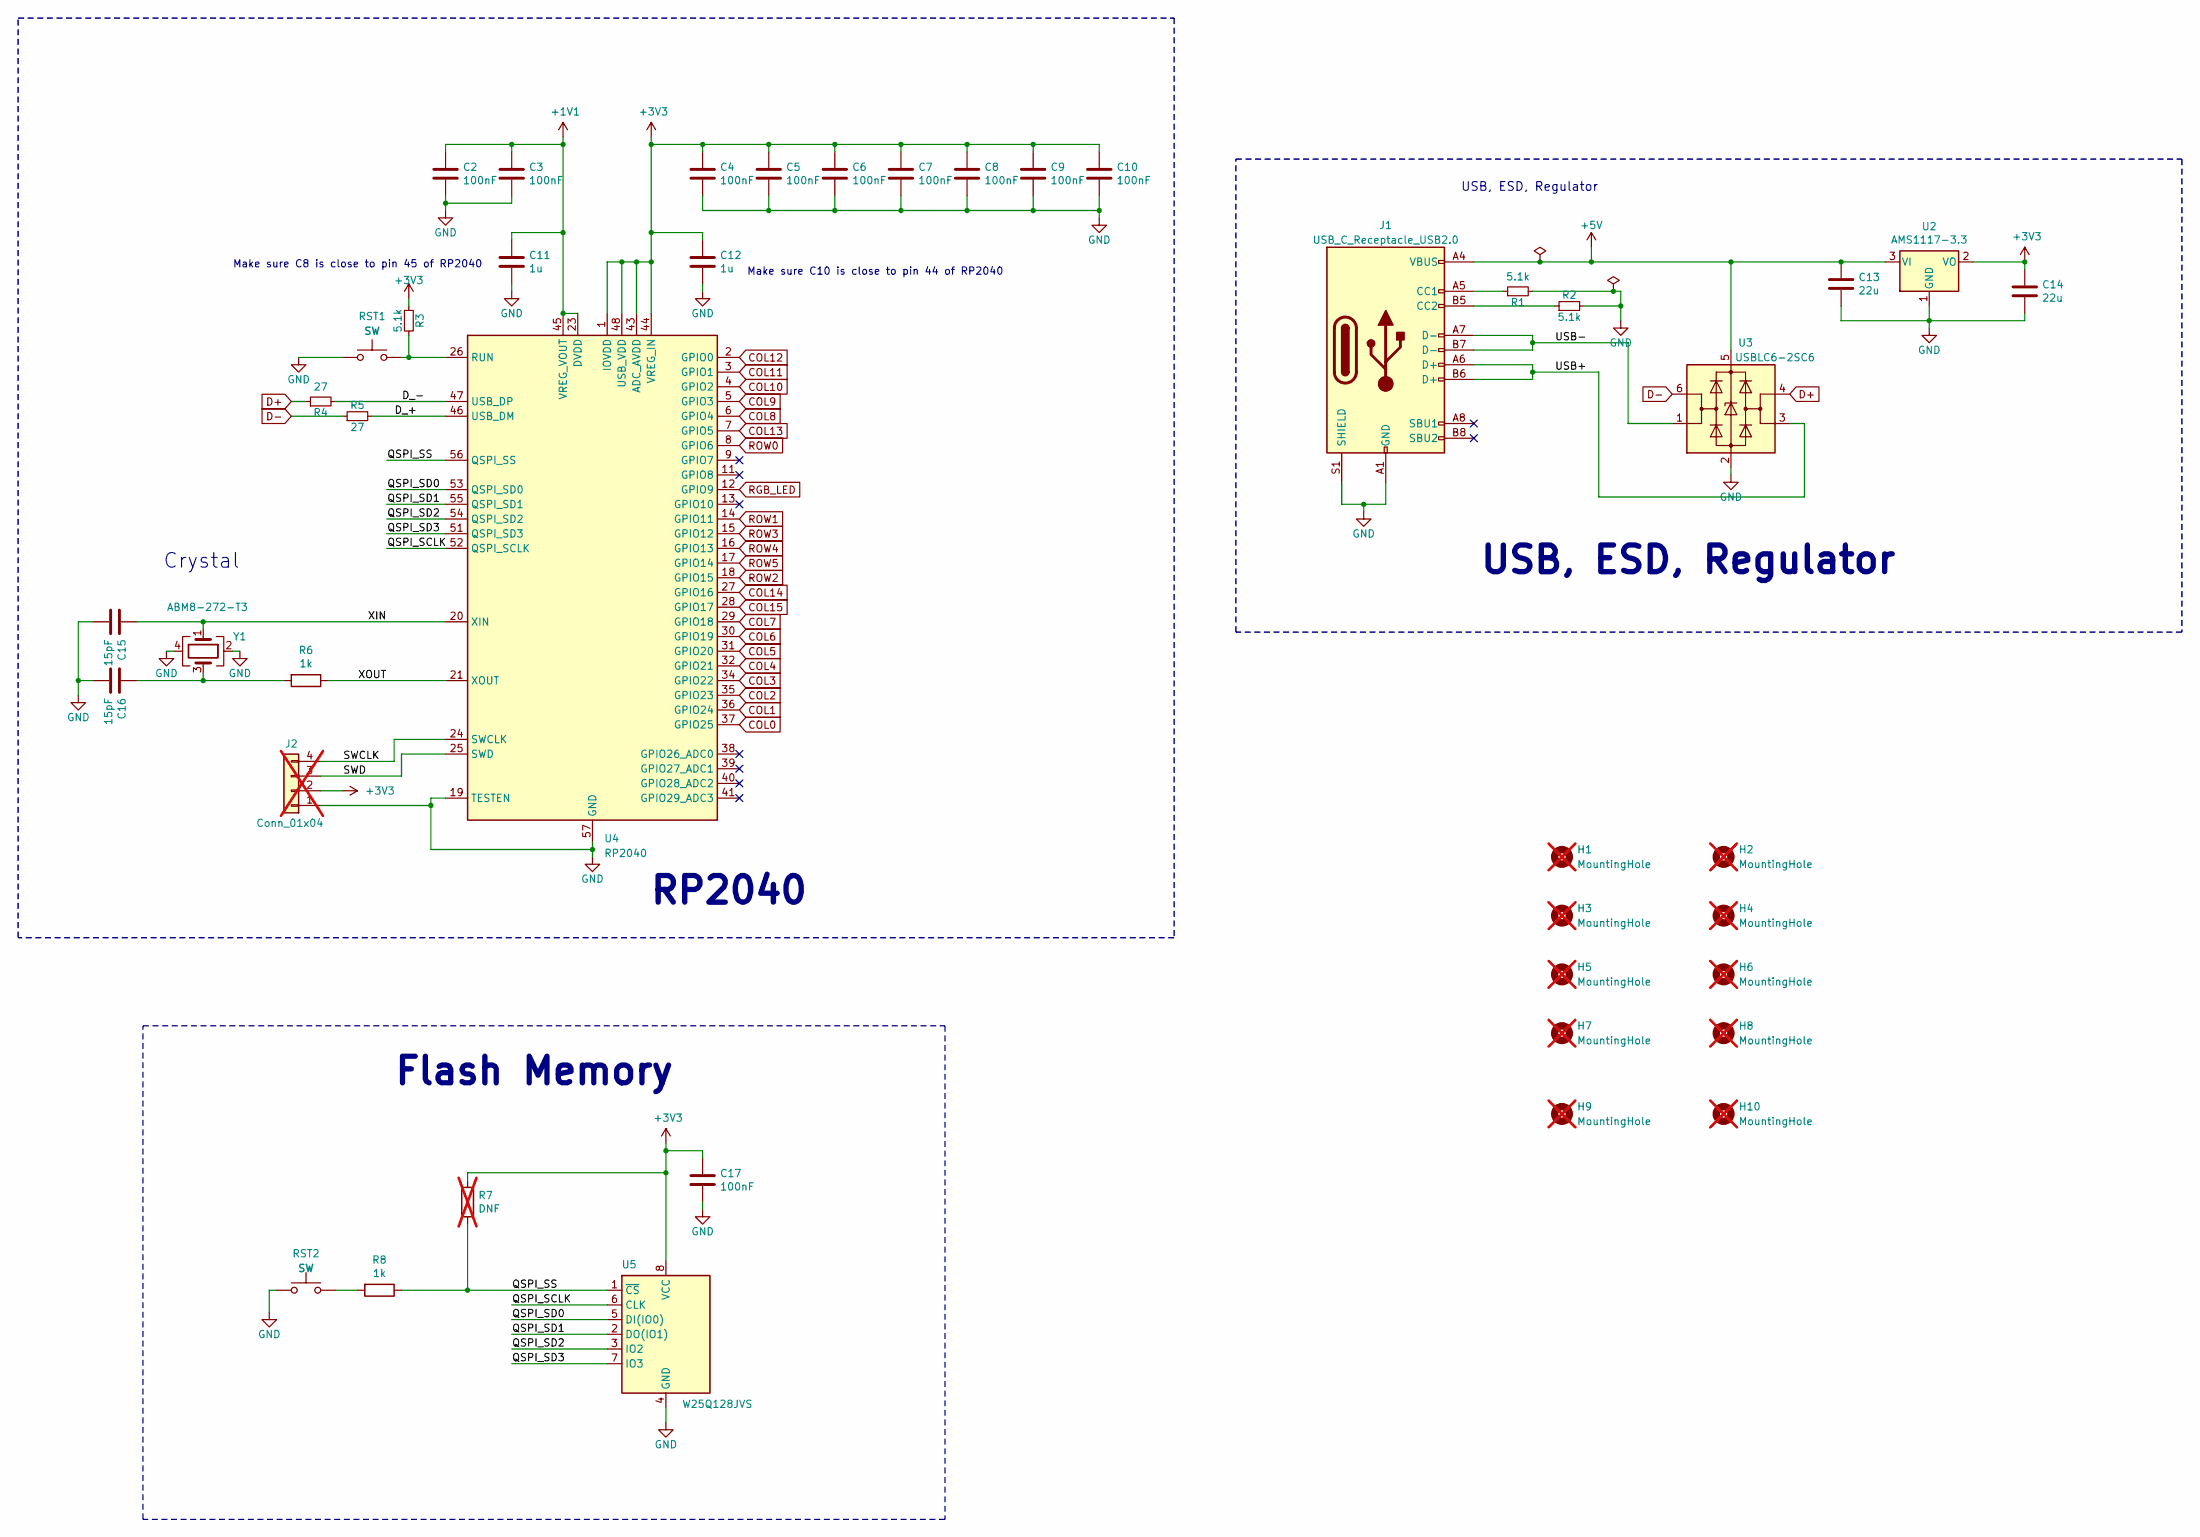
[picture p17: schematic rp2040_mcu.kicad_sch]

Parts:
C2, C3, C4, C5, C6, C7, C8, C9, C10, C17: 100nF; C_0402_1005Metric; MFR.Part # CL05B104KO5NNNC; LCSC C1525
C11, C12: 1u; C_0402_1005Metric; MFR.Part # CL05A105KA5NQNC; LCSC C52923
C13, C14: 22u; C_0603_1608Metric; MFR.Part # CL10A226MQ8NRNC; LCSC C59461
C15, C16: 15pF; C_0402_1005Metric; MFR.Part # 0402CG150J500NT; LCSC C1548
H1, H2, H3, H4, H5, H6, H7, H8, H9, H10: MountingHole; MountingHole_2.2mm_M2; not fitted
J1: USB_C_Receptacle_USB2.0; USB_C_Receptacle_HRO_TYPE-C-31-M-12; LCSC C165948
J2: Conn_01x04; PinHeader_1x04_P2.00mm_Vertical; MFR.Part # DNP; JLCPCB part# DNP; not fitted
R1, R2: 5.1k; R_0402_1005Metric_Pad0.72x0.64mm_HandSolder; LCSC C25905
R3: 5.1k; R_0402_1005Metric_Pad0.72x0.64mm_HandSolder; MFR.Part # 0402WGF5101TCE; LCSC C25905
R4, R5: 27; R_0402_1005Metric_Pad0.72x0.64mm_HandSolder; MFR.Part # 0402WGF270JTCE; LCSC C226392
R6: 1k; R_0402_1005Metric; MFR.Part # 0402WGF1001TCE; LCSC C11702
R7: DNF; R_0402_1005Metric; MFR.Part # DNP; JLCPCB part# DNP; not fitted
R8: 1k; R_0402_1005Metric; LCSC C11702
RST1: SW; SW_SPST_SKQG_WithStem; MFR.Part # TS5215A 250gf 025; LCSC C5140332
RST2: SW; SW_SPST_SKQG_WithStem; MFR.Part # TS5215A 250gf 025; JLC C5140332
U2: AMS1117-3.3; SOT-223-3_TabPin2; MFR.Part # AMS1117-3.3; LCSC C6186
U3: USBLC6-2SC6; SOT-23-6; MFR.Part # USBLC6-2SC6; LCSC C558442
U4: RP2040; QFN-56-1EP_7x7mm_P0.4mm_EP3.2x3.2mm; MFR.Part # RP2040; LCSC C2040
U5: W25Q128JVS; SOIC127P790X216-8N; MFR.Part # W25Q128JVSIQ; LCSC C97521
Y1: ABM8-272-T3; Crystal_SMD_3225-4Pin_3.2x2.5mm; MFR.Part # ABM8-272-T3; LCSC C20625731

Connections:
+1V1: C2.1, C3.1, C11.1, U4.23 (DVDD), U4.45 (VREG_VOUT), U4.50 (DVDD)
+3V3: C4.1, C5.1, C6.1, C7.1, C8.1, C9.1, C10.1, C12.1, C14.1, C17.1, J2.2, R3.1, R7.1, U2.2 (VO), U4.1 (IOVDD), U4.10 (IOVDD), U4.22 (IOVDD), U4.33 (IOVDD), U4.42 (IOVDD), U4.43 (ADC_AVDD), U4.44 (VREG_IN), U4.48 (USB_VDD), U4.49 (IOVDD), U5.8 (VCC)
+5V: C13.1, J1.A4 (VBUS), J1.A9 (VBUS), J1.B4 (VBUS), J1.B9 (VBUS), U2.3 (VI), U3.5 (VBUS); also elsewhere on the board
/RP2040 MCU/D_+: R5.2, U4.46 (USB_DM)
/RP2040 MCU/D_-: R4.2, U4.47 (USB_DP)
/RP2040 MCU/QSPI_SCLK: U4.52 (QSPI_SCLK), U5.6 (CLK)
/RP2040 MCU/QSPI_SD0: U4.53 (QSPI_SD0), U5.5 (DI(IO0))
/RP2040 MCU/QSPI_SD1: U4.55 (QSPI_SD1), U5.2 (DO(IO1))
/RP2040 MCU/QSPI_SD2: U4.54 (QSPI_SD2), U5.3 (IO2)
/RP2040 MCU/QSPI_SD3: U4.51 (QSPI_SD3), U5.7 (IO3)
/RP2040 MCU/QSPI_SS: R7.2, R8.1, U4.56 (QSPI_SS), U5.1 (~CS)
/RP2040 MCU/SWCLK: J2.4, U4.24 (SWCLK)
/RP2040 MCU/SWD: J2.3, U4.25 (SWD)
/RP2040 MCU/USB+: J1.A6 (D+), J1.B6 (D+), U3.3 (I/O2)
/RP2040 MCU/USB-: J1.A7 (D-), J1.B7 (D-), U3.1 (I/O1)
/RP2040 MCU/XIN: C15.1, U4.20 (XIN), Y1.1
/RP2040 MCU/XOUT: R6.1, U4.21 (XOUT)
COL0: U4.37 (GPIO25); also elsewhere on the board
COL1: U4.36 (GPIO24); also elsewhere on the board
COL2: U4.35 (GPIO23); also elsewhere on the board
COL3: U4.34 (GPIO22); also elsewhere on the board
COL4: U4.32 (GPIO21); also elsewhere on the board
COL5: U4.31 (GPIO20); also elsewhere on the board
COL6: U4.30 (GPIO19); also elsewhere on the board
COL7: U4.29 (GPIO18); also elsewhere on the board
COL8: U4.6 (GPIO4); also elsewhere on the board
COL9: U4.5 (GPIO3); also elsewhere on the board
COL10: U4.4 (GPIO2); also elsewhere on the board
COL11: U4.3 (GPIO1); also elsewhere on the board
COL12: U4.2 (GPIO0); also elsewhere on the board
COL13: U4.7 (GPIO5); also elsewhere on the board
COL14: U4.27 (GPIO16); also elsewhere on the board
COL15: U4.28 (GPIO17); also elsewhere on the board
D+: R4.1, U3.4 (I/O2)
D-: R5.1, U3.6 (I/O1)
GND: C2.2, C3.2, C4.2, C5.2, C6.2, C7.2, C8.2, C9.2, C10.2, C11.2, C12.2, C13.2, C14.2, C15.2, C16.2, C17.2, J1.A1 (GND), J1.A12 (GND), J1.B1 (GND), J1.B12 (GND), J1.S1 (SHIELD), J2.1, R1.2, R2.2, RST1.1, RST2.2, U2.1 (GND), U3.2 (GND), U4.19 (TESTEN), U4.57 (GND), U5.4 (GND), Y1.2, Y1.4; also elsewhere on the board
unnamed: C16.1, R6.2, Y1.3
unnamed: J1.A5 (CC1), R1.1
unnamed: J1.B5 (CC2), R2.1
unnamed: R8.2, RST2.1
unnamed: R3.2, RST1.2, U4.26 (RUN)
RGB_LED: U4.12 (GPIO9); also elsewhere on the board
ROW0: U4.8 (GPIO6); also elsewhere on the board
ROW1: U4.14 (GPIO11); also elsewhere on the board
ROW2: U4.18 (GPIO15); also elsewhere on the board
ROW3: U4.15 (GPIO12); also elsewhere on the board
ROW4: U4.16 (GPIO13); also elsewhere on the board
ROW5: U4.17 (GPIO14); also elsewhere on the board

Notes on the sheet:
USB, ESD, Regulator
Flash Memory
Make sure C10 is close to pin 44 of RP2040
Crystal
RP2040
Make sure C8 is close to pin 45 of RP2040

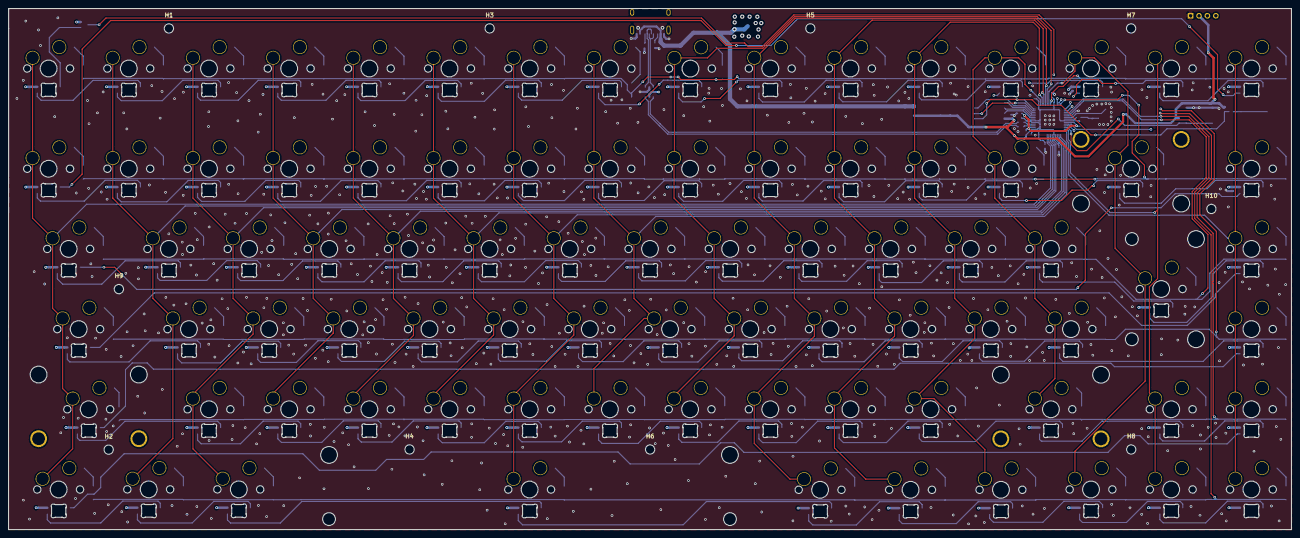
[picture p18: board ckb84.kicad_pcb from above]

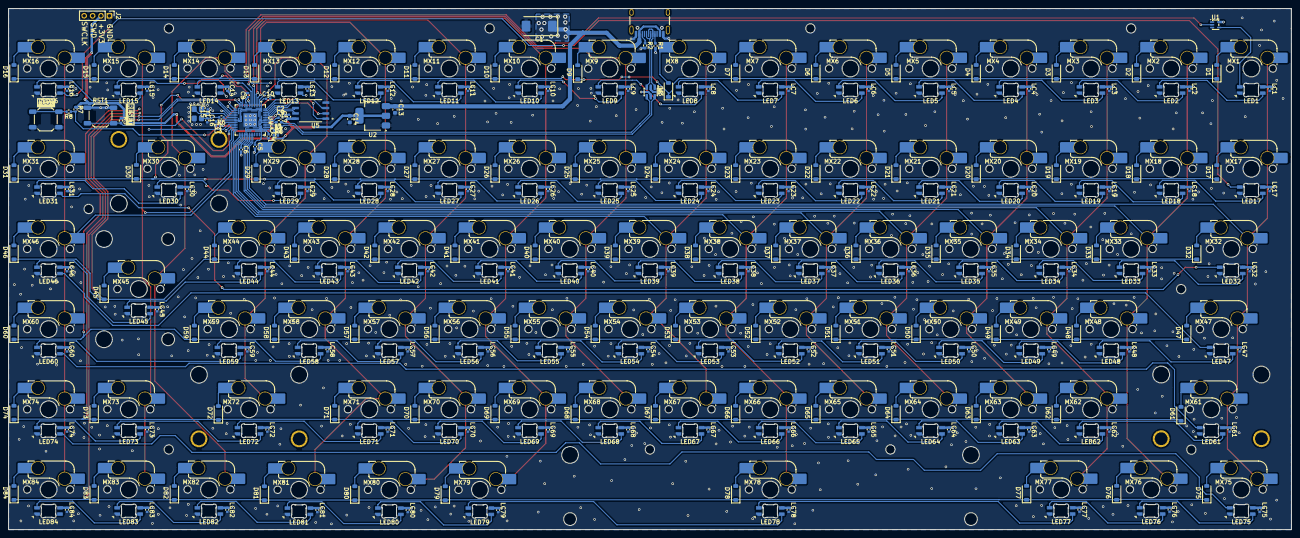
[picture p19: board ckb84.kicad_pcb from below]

Board: 4 copper layers, 304.8 x 123.8 mm, 388 parts (377 on the bottom side), 216 nets.

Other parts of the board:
kibuzzard-6A6FB6DB: G***; kibuzzard-6A6FB6DB
kibuzzard-6A6FB680: G***; kibuzzard-6A6FB680

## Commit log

2026-10-04 Add source files
    [BOM File.csv, bottom_case.step, ckb84.kicad_pcb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]
2026-10-15 Adjust magnet holes
